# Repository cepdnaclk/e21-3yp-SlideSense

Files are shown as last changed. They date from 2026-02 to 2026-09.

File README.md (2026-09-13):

# SlideSense

### AI-Enhanced IoT Landslide Monitoring & Early Warning System

<p align="center">
  SlideSense Logo
</p>

<p align="center">
  <b>Early Detection. Safe Tomorrow.</b>
</p>

<p align="center">
  
  
  
  
</p>

<p align="center">
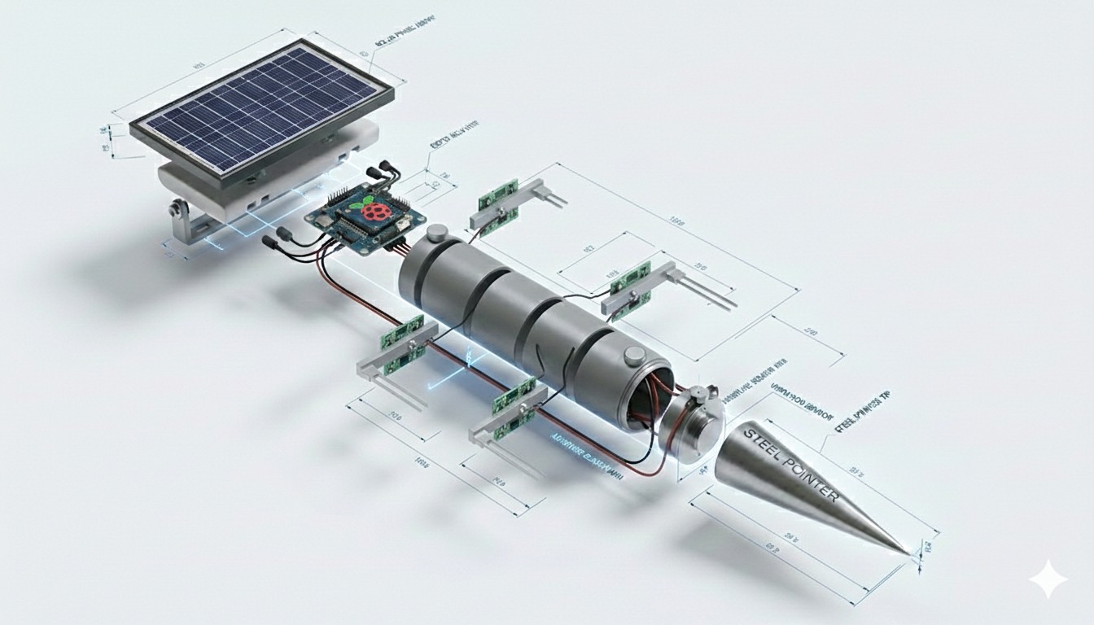
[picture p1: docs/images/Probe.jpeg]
SlideSense Sensor Probe
  
</p>

## Table of Contents

1. [Introduction](#introduction)
2. [Project Objectives](#project-objectives)
3. [System Overview](#system-overview)
4. [Overall System Architecture](#overall-system-architecture)
5. [Hardware Components](#hardware-components)
6. [Final Hardware Prototype](#final-hardware-prototype)
7. [Data Flow](#data-flow)
8. [Cloud Architecture](#cloud-architecture)
9. [Monitoring Dashboard](#monitoring-dashboard)
10. [Software & Technology Stack](#software--technology-stack)
11. [Testing & Validation](#testing--validation)
12. [Project Timeline](#project-timeline)
13. [Team](#team)
14. [Future Work](#future-work)
15. [Links](#links)

# Introduction

Landslides are a major natural hazard in mountainous and high-rainfall regions of Sri Lanka. Heavy rainfall and increasing soil moisture can gradually reduce slope stability and create potentially dangerous conditions.

**SlideSense** is an IoT-based landslide monitoring and early-warning system developed to continuously observe environmental conditions associated with landslide risk.

The system integrates:

- Multi-depth soil moisture sensing
- Rainfall monitoring
- ESP32-based embedded processing
- GPS positioning
- Cellular communication
- Solar-powered field operation
- AWS cloud infrastructure
- Historical sensor data storage
- Web-based monitoring and visualization
- Risk analysis and early-warning capabilities

SlideSense provides an end-to-end monitoring pipeline from the physical slope to a cloud-connected monitoring dashboard.

# Project Objectives

The main objective of SlideSense is to develop a practical IoT platform capable of continuously monitoring environmental parameters related to landslide risk.

The system aims to:

- Monitor soil moisture at multiple positions below the ground
- Measure rainfall continuously
- Collect and process sensor measurements using an ESP32
- Transmit field data to the cloud
- Store sensor measurements for future analysis
- Visualize real-time and historical data
- Identify potentially dangerous environmental conditions
- Support early-warning mechanisms
- Operate using an independent solar-powered field station

# System Overview

SlideSense consists of four major physical and software subsystems.

### 1. Subsurface Sensor Probe

The sensor probe is inserted into the monitored slope and contains soil moisture sensors positioned at different locations along the probe.

Measurements from multiple sensing points provide a better representation of subsurface soil conditions than a single surface measurement.

### 2. Rainfall Monitoring System

A tipping-bucket rain gauge measures accumulated rainfall.

A Hall-effect sensor detects each bucket tip.

Each tip corresponds to approximately:

> **0.173 mm of rainfall**

The ESP32 counts the detected tipping events and calculates the accumulated rainfall.

### 3. Main Control Unit

The main control unit contains the electronics required for sensor acquisition, communication, positioning, and power management.

The unit integrates:

- ESP32
- GPS module
- SIM / cellular communication module
- Buck converter
- MPPT solar charge controller
- Sensor connections
- Power-management circuitry

### 4. Web & Cloud Platform

Sensor measurements are transmitted to the cloud, where they can be processed, stored, analyzed, and accessed through the SlideSense monitoring dashboard.

# Overall System Architecture

The overall architecture connects the physical monitoring station with cloud services and the user-facing monitoring platform.

<p align="center">
  SlideSense Architecture
</p>

# Hardware Components

| Component | Function |
|---|---|
| **ESP32** | Main embedded controller |
| **Soil Moisture Sensors** | Monitor subsurface soil moisture |
| **Tipping Bucket Rain Gauge** | Measure accumulated rainfall |
| **Hall-Effect Sensor** | Detect tipping-bucket events |
| **GPS Module** | Obtain monitoring-node location |
| **SIM / Cellular Module** | Remote communication |
| **Solar Panel** | Renewable power source |
| **MPPT Charge Controller** | Manage solar charging |
| **Buck Converter** | Regulate supply voltage |
| **Battery** | Store energy for field operation |
| **Sensor Probe** | Houses subsurface sensing elements |
| **Main Control Unit** | Houses control and communication electronics |

# Final Hardware Prototype

## Sensor Probe

<p align="center">
  SlideSense Sensor Probe
</p>

The final SlideSense probe contains multiple soil moisture sensing positions.

The probe is designed to be placed vertically in the monitored ground so that environmental conditions can be measured below the surface.

## Tipping Bucket Rain Gauge

<p align="center">
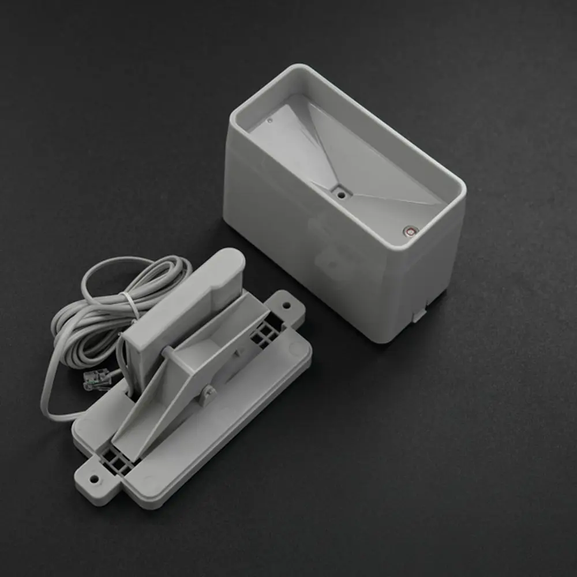
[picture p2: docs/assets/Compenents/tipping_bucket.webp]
SlideSense Tipping Bucket Rain Gauge
  
</p>

Rainfall is monitored using a tipping-bucket mechanism.

When the bucket tips, the Hall-effect sensor detects the event and sends it to the ESP32.

The system converts the number of detected tips into accumulated rainfall.

> **Rainfall per tip: approximately 0.173 mm**

## Main Control Unit

<p align="center">
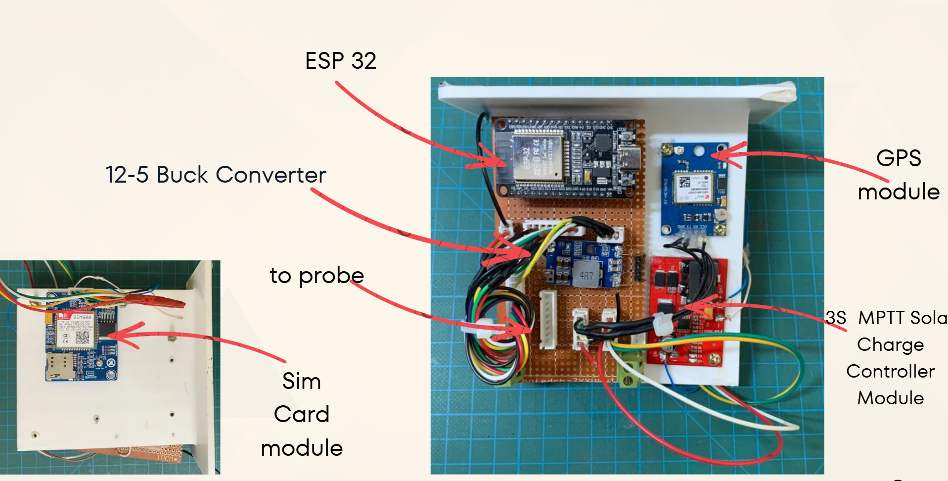
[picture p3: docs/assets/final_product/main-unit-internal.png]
SlideSense Main Control Unit
  
</p>

The main control unit integrates the electronic components required for data acquisition and communication.

Major components include:

- ESP32
- GPS module
- SIM / cellular module
- Buck converter
- MPPT solar charge controller
- Probe connection
- Power and sensor wiring

## Solar-Powered Field Station

<p align="center">
  SlideSense Solar Powered Field Station
</p>

The final SlideSense monitoring station combines the main control unit, solar panel, rainfall monitoring equipment, communication hardware, and underground sensor probe.

The solar-powered design allows the monitoring station to operate in locations where conventional power infrastructure may not be available.

# Data Flow

SlideSense follows an end-to-end IoT data pipeline.

```text
Environmental Conditions
          │
          ▼
   Physical Sensors
          │
          ▼
        ESP32
          │
          ▼
 Cellular Communication
          │
          ▼
     AWS IoT Core
          │
          ▼
   Cloud Processing
          │
     ┌────┴────┐
     │         │
     ▼         ▼
 Analysis   Database
     │         │
     └────┬────┘
          │
          ▼
    Web Dashboard
          │
          ▼
  Monitoring / Alerts
```

### Data Processing Steps

1. Soil moisture sensors measure subsurface conditions.
2. The tipping bucket measures rainfall.
3. The ESP32 collects the sensor measurements.
4. GPS information identifies the monitoring-node location.
5. Data is transmitted through the communication system.
6. Telemetry is published to AWS IoT Core using MQTT.
7. Cloud services process incoming measurements.
8. Sensor readings are stored for historical analysis.
9. The dashboard retrieves and displays the data.
10. Risk conditions can be evaluated to support early warnings.

# Cloud Architecture

The cloud layer connects the physical SlideSense field station with the monitoring dashboard.

## AWS IoT Core

AWS IoT Core receives telemetry published by the ESP32 using the MQTT protocol.

It provides the main communication entry point between the deployed monitoring station and cloud services.

## Cloud Processing

Incoming measurements can be processed to:

- Validate sensor readings
- Calculate derived measurements
- Analyze environmental conditions
- Evaluate configured thresholds
- Determine risk levels
- Trigger warning mechanisms

## Data Storage

Sensor readings are stored together with their timestamps.

This enables the system to support both:

**Real-Time Monitoring**

and

**Historical Data Analysis**

Historical measurements are particularly useful for identifying how environmental conditions change over longer periods.

# Monitoring Dashboard

SlideSense includes a dedicated web-based monitoring dashboard.

The dashboard provides a user-friendly interface for viewing and analyzing the measurements collected by the field station.

<p align="center">
  SlideSense Monitoring Dashboard
</p>

## Dashboard Features

### Real-Time Monitoring

The dashboard displays the latest measurements received from the field monitoring station.

### Sensor Charts

Sensor readings are visualized using time-series charts, making environmental changes easier to identify.

### Historical Data

Users can retrieve previously recorded measurements for further analysis.

### Trend Analysis

Current and historical readings can be compared to understand changes in environmental conditions.

### Risk Monitoring

Processed sensor information can be used to present the current environmental or landslide-risk condition.

## Live Dashboard

<p align="center">

[**Open SlideSense Live Dashboard →**](YOUR_DASHBOARD_URL)

</p>

# Software & Technology Stack

## Embedded System

- ESP32
- C / C++
- Arduino Framework
- Sensor interfacing
- MQTT communication
- GPS integration
- Cellular communication

## Cloud

- AWS IoT Core
- AWS Lambda
- DynamoDB
- MQTT

## Backend

- REST API
- Sensor-data retrieval
- Historical-data access
- Cloud integration
- Risk-analysis logic

## Frontend

- Web-based monitoring dashboard
- Responsive interface
- Real-time sensor visualization
- Time-series charts
- Historical data visualization
- Risk-status monitoring

<p align="center">
  SlideSense Software Stack
</p>

# Risk Analysis

SlideSense combines multiple environmental parameters to support landslide-risk analysis.

```text
        Soil Moisture
             +
          Rainfall
             +
   Environmental Data
             │
             ▼
       Data Analysis
             │
             ▼
      Risk Evaluation
             │
       ┌─────┼─────┐
       │     │     │
       ▼     ▼     ▼
    NORMAL MODERATE HIGH
             │
             ▼
       Warning System
```

Rather than depending on a single measurement, the system can evaluate multiple environmental conditions together.

# Testing & Validation

Testing was performed progressively from individual sensors to the complete cloud-connected system.

## Hardware Testing

Hardware verification included:

- Power and wiring checks
- Sensor connection testing
- ESP32 operation
- Soil moisture sensor response
- Tipping-bucket operation
- Hall-effect sensor detection
- GPS module communication
- Cellular communication
- Power-management testing
- Solar-system integration

## Soil Moisture Testing

The soil moisture sensors were tested under different moisture conditions.

Water was applied during testing and the corresponding changes in sensor readings were observed to verify sensor response.

## Rainfall Testing

The tipping bucket was tested using controlled water input.

Each physical bucket tip was checked against the corresponding digital event detected by the ESP32.

## Communication Testing

Sensor measurements were transmitted from the ESP32 to the cloud to verify the communication pipeline.

## Dashboard Testing

Cloud-stored measurements were retrieved and displayed through the monitoring dashboard.

## End-to-End Validation

The complete system was tested through the following path:

```text
Sensor
  ↓
ESP32
  ↓
Communication
  ↓
AWS IoT Core
  ↓
Cloud Processing
  ↓
Database
  ↓
Backend
  ↓
Web Dashboard
```

This verifies the complete flow from physical environmental measurement to user-facing visualization.

# Project Timeline

The project was completed through four major development milestones.

### Milestone 01
**Proposal & Planning**

- Problem identification
- Background research
- Initial system architecture
- Component selection

### Milestone 02
**Hardware Development & Testing**

- Sensor testing
- ESP32 integration
- Rainfall monitoring
- Probe development
- Communication testing

### Milestone 03
**Working Prototype**

- Hardware integration
- Cloud communication
- Data storage
- Backend development
- Dashboard development

### Milestone 04
**Final System**

- Final probe assembly
- Main control unit
- Solar-powered monitoring stand
- Dashboard integration
- System testing
- Documentation
- Final demonstration

# Team

SlideSense was developed as a Third-Year Project at the **Department of Computer Engineering, Faculty of Engineering, University of Peradeniya**.

| Reg. No. | Team Member | Email |
|---|---|---|
| **E/21/087** | Shihara Dewagedara | [e21087@eng.pdn.ac.lk](mailto:e21087@eng.pdn.ac.lk) |
| **E/21/138** | Fikry M.N.M. | [e21138@eng.pdn.ac.lk](mailto:e21138@eng.pdn.ac.lk) |
| **E/21/302** | Sahandi Perera | [e21302@eng.pdn.ac.lk](mailto:e21302@eng.pdn.ac.lk) |
| **E/21/452** | Zaid M.R.M. | [e21452@eng.pdn.ac.lk](mailto:e21452@eng.pdn.ac.lk) |

<p align="center">
  <b>Department of Computer Engineering</b><br>
  Faculty of Engineering<br>
  University of Peradeniya<br>
  Sri Lanka
</p>

# Future Work

SlideSense provides a foundation that can be extended through future research and development.

Potential improvements include:

- Machine-learning-based landslide-risk prediction
- Sensor-fusion-based risk estimation
- Long-term field deployment and validation
- Deployment of multiple monitoring stations
- Improved weather-resistant enclosures
- Additional geological sensors
- Advanced anomaly detection
- Mobile application development
- Location-based community warnings
- Integration with additional meteorological data
- Improved predictive models using historical datasets

# Links

### Project Website
🌐 [Visit the SlideSense Project Website](YOUR_PROJECT_WEBSITE_URL)

### Live Monitoring Dashboard
📊 [Open the SlideSense Dashboard](YOUR_DASHBOARD_URL)

### GitHub Repository
💻 [SlideSense Source Code](YOUR_GITHUB_REPOSITORY_URL)

---

<p align="center">
  SlideSense Logo
</p>

<p align="center">
  <b>SlideSense</b><br>
  AI-Enhanced IoT Landslide Monitoring & Early Warning System<br><br>
  Department of Computer Engineering<br>
  Faculty of Engineering<br>
  University of Peradeniya
</p>

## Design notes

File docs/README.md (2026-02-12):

---
layout: home
permalink: index.html
repository-name: e21-3yp-SlideSense
title: SlideSense
---

<p align="center">
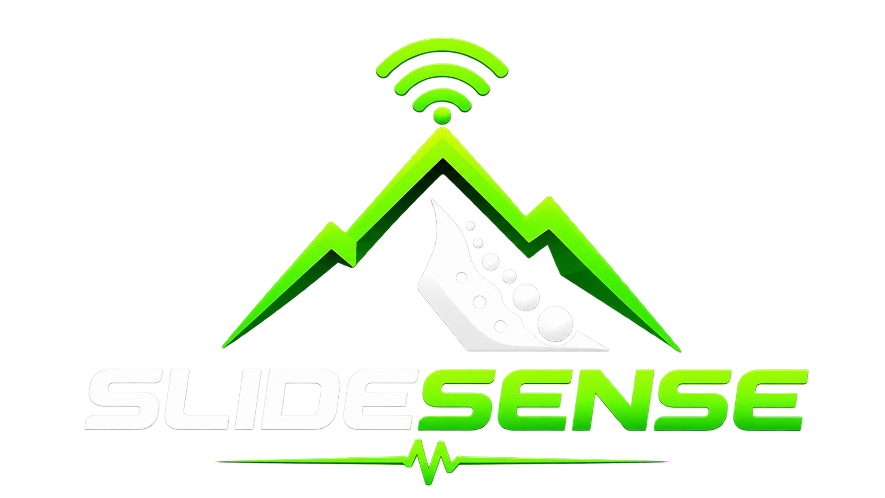
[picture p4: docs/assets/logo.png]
  
</p>

<p align="center">
  
</p>

<p align="center">
  
</p>

## Team
- E/21/087, Shihara Dewagedara, [e21087@eng.pdn.ac.lk](mailto:e21087@eng.pdn.ac.lk)
- E/21/138, Fikry M.N.M., [e21138@eng.pdn.ac.lk](mailto:e21138@eng.pdn.ac.lk)
- E/21/302, Sahandi Perera, [e21302@eng.pdn.ac.lk](mailto:e21302@eng.pdn.ac.lk)
- E/21/452, Zaid M.R.M., [e21452@eng.pdn.ac.lk](mailto:e21452@eng.pdn.ac.lk)

#### Table of Contents

1. [Introduction](#introduction)
2. [Overall System Architecture](#overall-system-architecture)
3. [Data Flow Architecture](#data-flow-architecture)
4. [Hardware Design](#hardware-design)
5. [Software Architecture & Stack](#software-architecture--stack)
6. [Project Timeline](#project-timeline)
7. [Testing & Validation](#testing--validation)
8. [Detailed Budget](#detailed-budget)
9. [Conclusion & Future Work](#conclusion--future-work)
10. [Links](#links)

## Introduction

Landslides remain a significant threat in hilly regions of Sri Lanka, often triggered by intense monsoon rainfall. **SlideSense** is an integrated IoT solution designed for real-time monitoring of high-risk slopes. 

The system moves beyond simple data logging by incorporating:
- **Redundant Communication:** Utilizing both Cloud (AWS/Firebase) and Local (Gateway) paths.
- **Edge Intelligence:** Real-time threshold analysis on the ESP32 to trigger immediate local sirens.
- **Resilience:** Designed to function even when external cellular networks fail during heavy storms.

## Overall System Architecture

SlideSense follows a **multi-layer IoT architecture**:

- **Perception Layer:** Distributed sensor nodes (ESP32) collect soil moisture, volumetric water content, and tilt data.
- **Network Layer:** Data is transmitted via MQTT protocol to a central Raspberry Pi gateway and subsequently to the AWS IoT Core.
- **Application Layer:** A React-based web dashboard and Firebase Cloud Messaging (FCM) provide localized alerts and historical data visualization for authorities.

<p align="center">
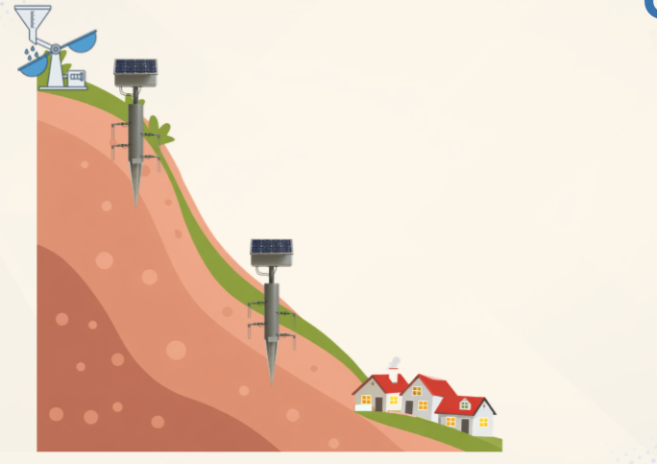
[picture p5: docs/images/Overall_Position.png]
  
</p>

## Data Flow Architecture

The system ensures reliable and redundant data transmission:

1. Sensors collect environmental data  
2. ESP32 performs edge analysis  
3. Data transmitted via LoRa / SIM900A  
4. Cloud (AWS/Firebase) processes & stores data  
5. Alerts triggered via Dashboard / SMS / FCM  

<p align="center">
  
</p>

##  Core Components

- **ESP32 WROOM 32U**
- **Capacitive Soil Moisture Sensors (x4)**
- **Tipping Bucket Rain Gauge**
- **High Sensitivity Microphone Sensor**
- **LoRa RA-02 SX1278 Module**
- **SIM900A GSM Module**
- **20W Solar Panel**
- **MPPT Charge Controller**
- **3.7V Li-Po Battery**

##  Power System

- MPPT Solar Charging
- 3.3V Regulation
- Deep Sleep Power Optimization

## Software Architecture & Stack

## Firmware
- Arduino Framework
- FreeRTOS Task Management
- MQTT Communication
- Deep Sleep Mode

##  Backend & Cloud
- AWS IoT Core / Firebase
- Mosquitto MQTT Broker
- Node.js Gateway (Optional)
- Firebase Cloud Messaging (Alerts)

##  Frontend
- React.js Dashboard
- Real-time Data Visualization
- Alert Monitoring Panel

## 🛠 Software Stack Diagram

<p align="center">
  
</p>

##  Project Timeline

The project was executed in four structured milestones:

- Milestone 01 – Proposal & Planning  
- Milestone 02 – Hardware Setup & Testing  
- Milestone 03 – Working Prototype  
- Milestone 04 – Final Product & Documentation  

<p align="center">
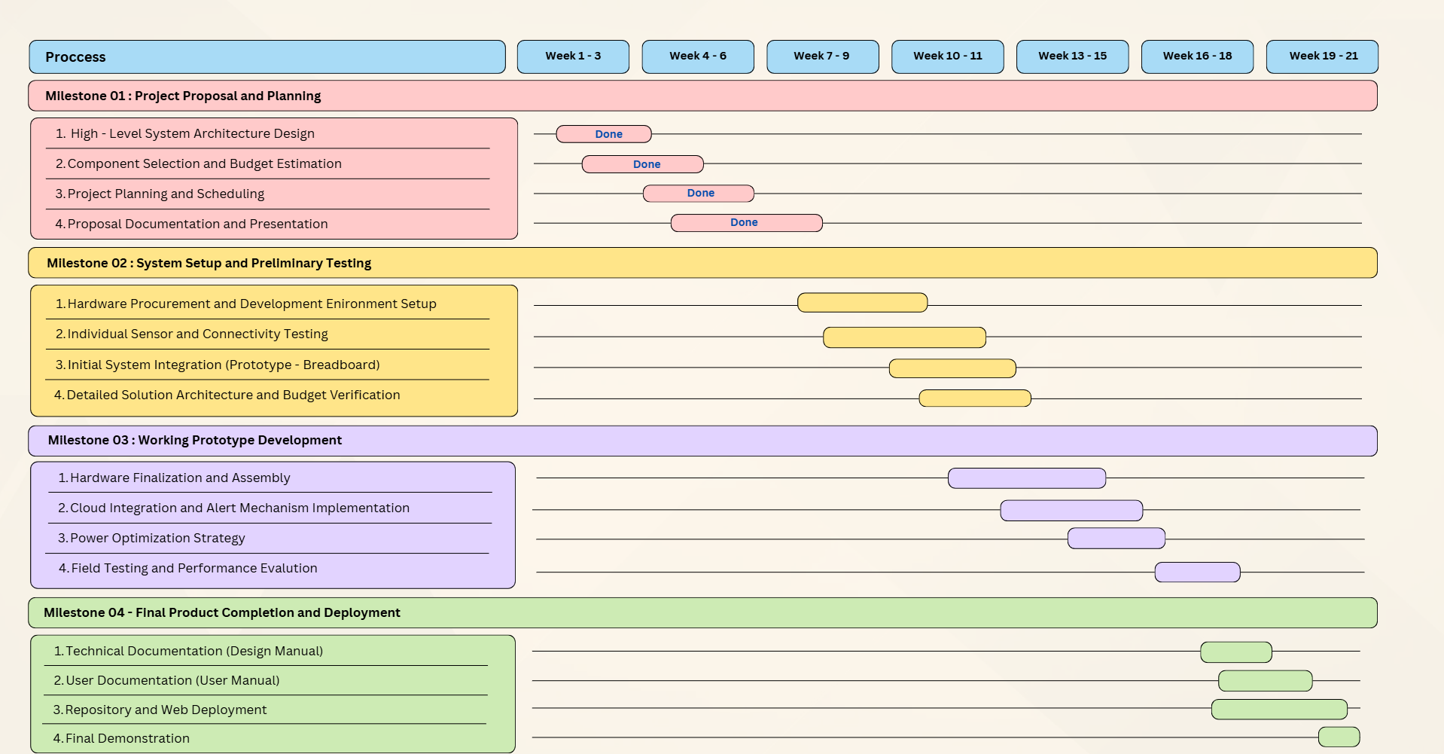
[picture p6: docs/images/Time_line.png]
  
</p>

## Testing & Validation

##  Hardware Testing
- Soil moisture calibration (dry vs saturated soil)
- Rain gauge pulse verification
- Battery discharge & deep sleep measurement

##  Connectivity Testing
- MQTT latency: < 2 seconds
- GSM fallback verification
- LoRa range testing in open field

##  Failover Testing
- Local gateway broadcast when WAN disconnected
- Alert triggering under simulated rainfall conditions

## Detailed Budget

| Item | Quantity | Unit Cost (LKR) | Total (LKR) |
| :--- | :---: | :---: | :---: |
| 20W Solar Panel | 1 | 3,350 | 3,350 |
| Li-Po Battery | 1 | 1,185 | 1,185 |
| MPPT Controller | 1 | 1,450 | 1,450 |
| Voltage Regulator | 1 | 120 | 120 |
| ESP32 | 1 | 1,860 | 1,860 |
| Soil Moisture Sensor | 4 | 290 | 1,160 |
| Tipping Bucket | 1 | 4,000 | 4,000 |
| LoRa Module | 1 | 1,500 | 1,500 |
| Microphone Sensor | 1 | 200 | 200 |
| SIM900A | 1 | 1,450 | 1,450 |
| **Total Cost** |  |  | **16,275 LKR** |

## Conclusion & Future Work

SlideSense demonstrates a **cost-effective, scalable, and resilient landslide monitoring system** integrating edge intelligence with cloud-based alerts.

### Future Enhancements
- LoRaWAN integration for extended mountainous coverage  
- Machine Learning (LSTM-based rainfall prediction)  
- IP67-rated rugged enclosure  
- Mobile application for public warning  

## Links

- [Project Repository](https://github.com/cepdnaclk/{{ page.repository-name }}){:target="_blank"}
- [Project Page](https://cepdnaclk.github.io/{{ page.repository-name}}){:target="_blank"}
- [Department of Computer Engineering](http://www.ce.pdn.ac.lk/)
- [University of Peradeniya](https://eng.pdn.ac.lk/)

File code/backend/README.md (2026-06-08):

# SlideSense Backend (Spring Boot)

This backend is initialized with:

- Java 21
- Spring Boot 3.5.13
- Maven wrapper
- Spring Web, Spring Data JPA, Validation, Actuator
- PostgreSQL + Flyway
- TimescaleDB-ready setup

## 1) Start local TimescaleDB

From this folder, run:

```bash
docker compose up -d
```

This creates:

- DB: `slidesense`
- User: `slidesense`
- Password: `slidesense`
- Port: `5432`

## 2) Build and test

```bash
./mvnw test
./mvnw -DskipTests package
```

The test profile excludes DB auto-configuration, so build checks run even if the DB is not running.

## 3) Run the app

```bash
./mvnw spring-boot:run
```

Defaults in `src/main/resources/application.properties` point to local TimescaleDB. Override via env vars if needed:

- `SPRING_DATASOURCE_URL`
- `SPRING_DATASOURCE_USERNAME`
- `SPRING_DATASOURCE_PASSWORD`
- `SERVER_PORT`

For a ready-to-edit template, copy `.env.example` to `.env` and adjust values for your machine.

Notes:

- `application.properties` is not a shell env file.
- It is the Spring Boot config file, and it can read environment variables using syntax like `${SPRING_DATASOURCE_URL:defaultValue}`.
- Use `.env` for local exported variables or editor tooling, and keep `.env.example` in git as the template.

## 4) Verify health

Open:

- `http://localhost:8080/actuator/health`

## 5) Swagger and security

- Swagger UI: `http://localhost:8080/swagger-ui.html`
- OpenAPI JSON: `http://localhost:8080/v3/api-docs`

Auth schemes:

- User APIs use Bearer JWT (`Authorization: Bearer <token>`)
- Public research APIs use API key header (`X-API-Key: <issued-key>`)

## 6) IntelliJ workflow

- Open the `code/backend` directory as a Maven project in IntelliJ.
- Use Maven tool window commands (`test`, `package`, `spring-boot:run`) or Run Configuration.

## 7) IntelliJ migration verification checklist

1. Start DB: `docker compose up -d`
2. Ensure schema is fresh only if needed:
  - Optional reset: `docker compose down -v` then `docker compose up -d`
3. Run app from IntelliJ (`BackendApplication`) or `./mvnw spring-boot:run`.
4. Confirm Flyway startup logs show `V1__enable_timescaledb.sql` and `V2__create_slidesense_schema.sql` applied (or already up to date).
5. Validate objects in PostgreSQL:
  - `\dt` should include relational tables and hypertables.
  - `\dm+` should show continuous aggregates.
  - `SELECT * FROM flyway_schema_history ORDER BY installed_rank;` should list V1 and V2 success.
6. Check API health: `http://localhost:8080/actuator/health`

## 8) Next for time-series schema

TimescaleDB extension is enabled through Flyway migration `V1__enable_timescaledb.sql`.
When you start defining your models, add a new migration to create hypertables, for example:

```sql
CREATE TABLE sensor_reading (
  id BIGSERIAL PRIMARY KEY,
  sensor_id TEXT NOT NULL,
  captured_at TIMESTAMPTZ NOT NULL,
  value DOUBLE PRECISION NOT NULL
);

SELECT create_hypertable('sensor_reading', 'captured_at', if_not_exists => TRUE);
```

## 9) Frontend Support Endpoints

New endpoints have been added to fully support the dynamic interactions required by the frontend application (`frontend-new`), replacing previously mocked data sources.

- **Probe Data (`ProbeDataController`)**
  - `GET /api/v1/probes/readings` - Returns paginated comprehensive sensor reading histories for all active probes.
  - `GET /api/v1/probes/latest` - Returns the latest captured snapshot for a specific probe.

- **Alerts (`AlertController`)**
  - `GET /api/v1/alerts` - Returns dynamically generated system alerts (e.g., critical movement detection based on tilt angle thresholds).

- **Dashboard Configurations (`DashboardController`)**
  - `GET /api/v1/dashboard/admin` - Returns admin thresholds, user lists, and security logs.
  - `GET /api/v1/dashboard/researcher` - Returns researcher analytics configurations.
  - `GET /api/v1/dashboard/resident` - Returns safety content and resident guidelines.
  - `GET /api/v1/dashboard/analytics-config` - Provides default metric options and time ranges for interactive graphs.

## 10) Authentication & Role-Based Access

The backend implements a robust, stateless JWT-based authentication system using Spring Security.

- **Login Flow**: Users authenticate via `POST /auth/login` by providing their `email` and `password`. The backend verifies the credentials against BCrypt password hashes in the database.
- **JWT Tokens**: Upon successful login, the backend issues an `accessToken` and `refreshToken` inside an `AuthResponse`. The frontend must include the access token in the `Authorization: Bearer <token>` header for all subsequent protected requests. The `AuthResponse` also cleanly returns the `user` object (including their `role`) so the frontend can properly route them to their dashboard.
- **Role-Based Access Control (RBAC)**: 
  - `JwtAuthenticationFilter` intercepts requests to validate the JWT and automatically populate the `SecurityContext`.
  - Endpoints are explicitly secured based on roles. For example, `GET /api/v1/probes/readings` requires `@PreAuthorize("hasRole('ADMIN') or hasRole('RESEARCHER')")` to prevent unauthorized broad data access.
  - Residents are restricted to `GET /api/v1/probes/my-readings`, where the `FrontendDataService` dynamically filters data to ensure they only receive readings for probes they have been explicitly granted access to via the `probe_access_grants` table.
- **CORS**: The application is configured with a global CORS policy allowing credentials, ensuring smooth communication between the React frontend and Spring Boot backend.

## 11) Soft Deletion of Probes

Probes (nodes) can be safely "removed" from the active system without deleting their historical data from the database.
- **Deactivation**: `DELETE /admin/probes/{probeId}` soft-deletes a probe by updating its `status` to `DEACTIVATED`. 
- **Data Integrity**: All associated `sensor_readings`, `rainfall_readings`, and `alerts` remain intact for historical queries.
- **Frontend Filtering**: The `FrontendDataService` automatically filters out `DEACTIVATED` probes from active live queries (`/api/v1/probes/readings` and `/api/v1/probes/my-readings`), ensuring removed nodes vanish from the active dashboard immediately.
- **Database Schema**: A new Flyway migration (`V5__add_deactivated_status_to_probes.sql`) modifies the PostgreSQL `CHECK` constraint on `probes.status` to safely permit the `DEACTIVATED` value.

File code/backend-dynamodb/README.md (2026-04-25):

# SlideSense DynamoDB Backend (Spring Boot)

A separate lightweight backend to read latest landslide sensor readings from DynamoDB.

## 1) What this provides

- `GET /api/landslide/latest` -> full latest record (m1, m2, m3, avg_moisture, rain, tilt, risk, lat, lng)
- `GET /api/landslide/latest/simple` -> simple key/value response (`moisture`, `rain`, `tilt`)
- `GET /api/landslide/health` -> health check

Default device ID is `LandslideProject/Prob01`, but you can override with query param:

- `/api/landslide/latest?deviceID=LandslideProject/Prob01`

## 2) AWS SDK dependency

Already added in [pom.xml](pom.xml):

- `software.amazon.awssdk:dynamodb:2.20.0`

## 3) Configure AWS credentials

Use one of these common options on your machine / server:

- Environment variables: `AWS_ACCESS_KEY_ID`, `AWS_SECRET_ACCESS_KEY`, `AWS_REGION`
- AWS profile in `~/.aws/credentials`
- IAM role (recommended for Elastic Beanstalk EC2)

The app uses region from `application.properties`:

- `app.dynamodb.region=ap-south-1`

## 4) Run locally

From this folder:

```bash
mvn clean package
mvn spring-boot:run
```

Test:

- `http://localhost:8080/api/landslide/latest`
- `http://localhost:8080/api/landslide/latest/simple`

## 5) Deploy to Elastic Beanstalk (Java platform)

1. Build JAR:
   - `mvn clean package`
2. Open AWS Elastic Beanstalk Console.
3. Create environment:
   - Tier: `Web server environment`
   - Platform: `Java`
   - Application code: upload `target/backend-dynamodb-0.0.1-SNAPSHOT.jar`
   - Preset: `Single instance (free tier eligible)`
4. IAM permissions (critical):
   - Find instance profile role used by Beanstalk (often `aws-elasticbeanstalk-ec2-role`)
   - Attach `AmazonDynamoDBReadOnlyAccess`

## 6) Optional env overrides in Beanstalk

Set these environment properties if needed:

- `APP_DYNAMODB_REGION=ap-south-1`
- `APP_DYNAMODB_TABLE_NAME=LandslideData`
- `APP_DYNAMODB_DEFAULT_DEVICE_ID=LandslideProject/Prob01`

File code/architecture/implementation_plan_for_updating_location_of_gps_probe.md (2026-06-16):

# Dynamic GPS Coordinates Update & Location Error Detection

## Background Context
Currently, probe coordinates (latitude and longitude) are only set/updated when the probe is initially created or when manually updated by an administrator via the map coordinate editor. GPS coordinates sent in probe telemetry readings are not tracked or saved.

We want to:
1. Automatically update the probe's location in the database when new telemetry readings arrive.
2. Detect if there is a "huge change" in coordinate values (exceeding a threshold of 0.01 degrees, i.e., ~1.1km).
3. If a huge change is detected, transition the probe status to `LOCATION_ERROR`, skip updating the coordinates, and make this visible in the frontend admin dashboard.
4. If the coordinates return to normal (within threshold), update them and revert status back to `ONLINE`.

---

## Proposed Changes

### Backend

#### [MODIFY] [ProbeStatus.java](file:///home/fikry/dev/e21-3yp-SlideSense/code/backend/src/main/java/com/slidesense/backend/model/enums/ProbeStatus.java)
- Add `LOCATION_ERROR` to the enum of probe statuses.

#### [MODIFY] [SqsSensorReadingMessage.java](file:///home/fikry/dev/e21-3yp-SlideSense/code/backend/src/main/java/com/slidesense/backend/dto/ingestion/SqsSensorReadingMessage.java)
- Add `latitude` and `longitude` fields to the SQS message record with `@JsonAlias` annotation supporting `lat`, `lng`, `latitude`, and `longitude`.

#### [MODIFY] [FrontendReadingDTO.java](file:///home/fikry/dev/e21-3yp-SlideSense/code/backend/src/main/java/com/slidesense/backend/dto/probe/FrontendReadingDTO.java)
- Add a `String status` field to the DTO so the frontend can receive the probe's current status (including `LOCATION_ERROR`).

#### [MODIFY] [FrontendDataService.java](file:///home/fikry/dev/e21-3yp-SlideSense/code/backend/src/main/java/com/slidesense/backend/service/FrontendDataService.java)
- Update instantiations of `FrontendReadingDTO` to populate the `status` field using `probe.getStatus().name()`.

#### [MODIFY] [SqsIngestionService.java](file:///home/fikry/dev/e21-3yp-SlideSense/code/backend/src/main/java/com/slidesense/backend/service/SqsIngestionService.java)
- In `processMessage`, if `message.latitude()` and `message.longitude()` are present:
  - If existing coordinates exist on the `Probe`:
    - Calculate absolute coordinate differences `diffLat` and `diffLng`.
    - If `diffLat > 0.01 || diffLng > 0.01`, set probe status to `LOCATION_ERROR`.
    - Otherwise, update probe's latitude and longitude and, if status was `LOCATION_ERROR`, revert it to `ONLINE`.
  - If no existing coordinates, update them directly and reset `LOCATION_ERROR` status if set.
  - Save the updated `Probe` entity.

#### [NEW] [SqsIngestionServiceTest.java](file:///home/fikry/dev/e21-3yp-SlideSense/code/backend/src/test/java/com/slidesense/backend/service/SqsIngestionServiceTest.java)
- Write unit tests for `SqsIngestionService` covering:
  - Coordinate update when no existing coordinates are present.
  - Normal coordinate update (within threshold).
  - Transition to `LOCATION_ERROR` when coordinate shift exceeds threshold.
  - Recovery to `ONLINE` and coordinate update when shifts fall back within threshold.

---

### Frontend

#### [MODIFY] [nodeService.js](file:///home/fikry/dev/e21-3yp-SlideSense/code/frontend-new/src/services/api/nodeService.js)
- Map the new `status` field from the reading data to the returned probe object.

#### [MODIFY] [NodesTab.jsx](file:///home/fikry/dev/e21-3yp-SlideSense/code/frontend-new/src/pages/admin/tabs/NodesTab.jsx)
- In the registered nodes table, render "Location Error" in red if `probe.status === 'LOCATION_ERROR'`.

#### [MODIFY] [ProbeDetailsPanel.jsx](file:///home/fikry/dev/e21-3yp-SlideSense/code/frontend-new/src/components/admin/ProbeDetailsPanel.jsx)
- Display a prominent error banner in the details panel when the selected probe has `status === 'LOCATION_ERROR'`.

---

## Verification Plan

### Automated Tests
- Run Backend unit/integration tests to verify that compilation and logic are correct:
  ```bash
  mvn test
  ```

### Manual Verification
- Trigger an HTTP ingestion message using `curl` with standard coordinates, and verify that the location coordinates update correctly on the database/frontend.
- Trigger an HTTP ingestion message with a large coordinate change, and verify that:
  - Status transitions to `LOCATION_ERROR`.
  - Coordinates are not modified.
  - The frontend displays "Location Error" on the nodes list and the details panel.

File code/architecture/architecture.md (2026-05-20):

# SlideSense — System Architecture

> IoT-Based Landslide Detection & Early Warning System

---

## 1. High-Level Overview

```
┌──────────────────────────────┐   MQTT    ┌──────────────────┐   IoT Rules  ┌────────────────┐
│  ESP32 / Raspberry Pi Node   ├─────────►│  AWS IoT Core     ├─────────────►│  AWS SQS Queue │
│  (Sensors + Wi-Fi + MQTT)    │          │  (Message Broker) │             │  (Buffer)      │
└──────────────────────────────┘          └──────────────────┘             └────────┬───────┘
                                                                                      │
                                                     ┌────────────────────────────────┘
                                                     │
                                                     ▼
                                          ┌──────────────────────┐
                                          │  SQS Consumer Worker │
                                          │  (Validation &       │
                                          │   Risk Analysis)     │
                                          └──────────┬───────────┘
                                                     │
                                    ┌────────────────┼─────────────────┐
                                    ▼                ▼                 ▼
                           ┌─────────────────┐ ┌──────────┐ ┌──────────────────┐
                           │   PostgreSQL +  │ │Notification│ Backend (FastAPI)
                           │   TimescaleDB   │ │  Service   │ on AWS EC2
                           │   (AWS RDS)     │ │(FCM/APNS)  │
                           └─────────────────┘ └──────────┘ └──────────┬───────┘
                                                                        │
                               ┌────────────────┬──────────────────────┤
                                ▼                ▼                      ▼
                       ┌──────────────────┐ ┌────────────────┐ ┌──────────────────┐
                       │  Mobile App      │ │  Admin Web     │ │  Research API    │
                       │  (Flutter)       │ │  Dashboard     │ │  /api/v1/public  │
                       │  HTTPS/REST      │ │  (React+Vite)  │ │  (API key auth)  │
                       └──────────────────┘ └────────────────┘ └──────────────────┘
```

**Telemetry flow:** ESP32/Raspberry Pi → MQTT → AWS IoT Core → IoT Rules Engine (routes to SQS) → SQS Queue → Spring Boot Backend (SQS Consumer) → Validation/Risk Analysis → DB Write + Notifications.

**API flow (external clients):** Mobile App, Admin Dashboard, Research API → Spring Boot Backend on EC2 → PostgreSQL + TimescaleDB.

---

ESP32 Payload structure
{
  "deviceTimeMs": 1716091208000, 
  "moisture": 45.2,
  "tiltAngle": 2.1,
  "vibrationMag": 0.05,
  "samplingMode": "ACTIVE",
  "rainfallMm": 12.5,
  "hwSerial": "ESP32-A1B2"
}

## 2. Database Structure

### 2.1 Schema Design

Two logical partitions inside a single PostgreSQL + TimescaleDB instance on AWS RDS.

#### A. Time-Series Store (TimescaleDB Hypertables)

```sql
-- Core sensor readings — converted to a hypertable on `recorded_at`
CREATE TABLE sensor_readings (
    id              BIGSERIAL,
    probe_id        UUID        NOT NULL REFERENCES probes(id),
    recorded_at     TIMESTAMPTZ NOT NULL,
    moisture        REAL,           -- % saturation
    tilt_angle      REAL,           -- degrees
    vibration_mag   REAL,           -- m/s²
    sampling_mode   VARCHAR(10)     -- 'normal' | 'burst'
);
SELECT create_hypertable('sensor_readings', 'recorded_at');

-- Rainfall readings — only probes with a rainfall gauge will publish these
CREATE TABLE rainfall_readings (
    id              BIGSERIAL,
    probe_id        UUID        NOT NULL REFERENCES probes(id),
    recorded_at     TIMESTAMPTZ NOT NULL,
    rainfall_mm     REAL
);
SELECT create_hypertable('rainfall_readings', 'recorded_at');

-- Continuous aggregate for dashboards / research API
CREATE MATERIALIZED VIEW sensor_aggregates
WITH (timescaledb.continuous) AS
SELECT
    probe_id,
    time_bucket('1 hour', recorded_at) AS bucket,
    AVG(moisture)      AS avg_moisture,
    MAX(vibration_mag) AS max_vibration
FROM sensor_readings
GROUP BY probe_id, bucket;

-- Continuous aggregate for rainfall-specific dashboards / research API
CREATE MATERIALIZED VIEW rainfall_aggregates
WITH (timescaledb.continuous) AS
SELECT
    probe_id,
    time_bucket('1 hour', recorded_at) AS bucket,
    SUM(rainfall_mm)   AS total_rainfall
FROM rainfall_readings
GROUP BY probe_id, bucket;
```

#### B. Relational Store (Standard PostgreSQL Tables)

```sql
CREATE TABLE users(
    id              UUID PRIMARY KEY DEFAULT gen_random_uuid(),
    email           VARCHAR(255)    UNIQUE NOT NULL,
    full_name       VARCHAR(160)    NOT NULL,
    phone_number    VARCHAR(30),
    address         TEXT,
    password_hash   TEXT            NOT NULL,       -- bcrypt
    role            VARCHAR(20)     NOT NULL DEFAULT 'resident',
                                    -- resident | admin | researcher
    registration_status VARCHAR(20)  NOT NULL DEFAULT 'pending',
                                   -- pending | approved | rejected | suspended
    approved_by     UUID            REFERENCES users(id),
    approved_at     TIMESTAMPTZ,
    created_at      TIMESTAMPTZ     DEFAULT now()
);

CREATE TABLE devices (
    id              UUID PRIMARY KEY DEFAULT gen_random_uuid(),
    user_id         UUID            NOT NULL REFERENCES users(id),
    device_token    TEXT            NOT NULL,       -- FCM / APNS push token
    is_active       BOOLEAN         DEFAULT true,
    registered_at   TIMESTAMPTZ     DEFAULT now()
);

CREATE TABLE probes (
    id              UUID PRIMARY KEY DEFAULT gen_random_uuid(),
    hw_serial       VARCHAR(64)     UNIQUE NOT NULL,
    firmware_ver    VARCHAR(20),
    latitude        DOUBLE PRECISION,
    longitude       DOUBLE PRECISION,
    status          VARCHAR(20)     DEFAULT 'online',  -- online | offline | maintenance
    installed_at    TIMESTAMPTZ     DEFAULT now()
);

CREATE TABLE registration_requests (
    id              UUID PRIMARY KEY DEFAULT gen_random_uuid(),
    user_id         UUID            NOT NULL REFERENCES users(id),
    requested_role  VARCHAR(20)     NOT NULL DEFAULT 'resident',
                                   -- resident | researcher
    probe_id        UUID            REFERENCES probes(id),
    reason          TEXT            NOT NULL,
    verification_notes TEXT,
    status          VARCHAR(20)     NOT NULL DEFAULT 'pending',
                                   -- pending | approved | rejected
    reviewed_by     UUID            REFERENCES users(id),
    reviewed_at     TIMESTAMPTZ,
    created_at      TIMESTAMPTZ     DEFAULT now(),
    CHECK (
        (requested_role = 'resident' AND probe_id IS NOT NULL) OR
        (requested_role = 'researcher' AND probe_id IS NULL)
    )
);

CREATE TABLE probe_access_grants (
    id              UUID PRIMARY KEY DEFAULT gen_random_uuid(),
    user_id         UUID            NOT NULL REFERENCES users(id),
    probe_id        UUID            NOT NULL REFERENCES probes(id),
    granted_by      UUID            NOT NULL REFERENCES users(id),
    granted_at      TIMESTAMPTZ     NOT NULL DEFAULT now(),
    revoked_at      TIMESTAMPTZ,
    -- Resident-specific probe grants; researchers are authorized by role.
    UNIQUE (user_id, probe_id)
);

CREATE TABLE alerts (
    id              UUID PRIMARY KEY DEFAULT gen_random_uuid(),
    probe_id        UUID            NOT NULL REFERENCES probes(id),
    level           SMALLINT        NOT NULL,       -- 1=Normal, 2=Warning, 3=Dangerous
    triggered_at    TIMESTAMPTZ     NOT NULL,
    resolved_at     TIMESTAMPTZ,
    details         JSONB
);

CREATE TABLE api_keys (
    id              UUID PRIMARY KEY DEFAULT gen_random_uuid(),
    owner_email     VARCHAR(255)    NOT NULL,
    key_hash        TEXT            NOT NULL,       -- SHA-256 of the issued key
    rate_limit      INT             DEFAULT 100,    -- requests/hour
    scopes          TEXT[]          DEFAULT '{read}',
    expires_at      TIMESTAMPTZ,
    created_at      TIMESTAMPTZ     DEFAULT now()
);
```

### 2.2 Data Retention Policy

| Granularity | Retention | Purpose |
|---|---|---|
| Raw readings (10 s – 15 min) | 90 days | Incident forensics |
| Aggregated readings | 2 years | Trend analysis / Research API |
| Daily aggregates | Indefinite | Long-term geological study |

Implemented via TimescaleDB `add_retention_policy()`.

---

## 3. Backend Software Architecture

### 3.1 Component Map

```
┌──────────────────────────────────────────────────────────────────────────┐
│                         AWS Environment                                  │
│                                                                          │
│  ┌──────────────────┐                                                   │
│  │  AWS IoT Core    │  IoT Rules Engine                                 │
│  │  (MQTT Broker)   ├──────────────────────────┐                       │
│  └──────────────────┘                          │                       │
│                                                  ▼                       │
│                                        ┌─────────────────┐              │
│                                        │   AWS SQS       │              │
│                                        │   Queue         │              │
│                                        └────────┬────────┘              │
│                                                  │                       │
│  ┌────────────────────────────────────────────────────────────────┐   │
│  │            Spring Boot Application (AWS EC2)                 │   │
│  │                                                               │   │
│  │  ┌──────────────────┐        ┌────────────────────────┐     │   │
│  │  │ SQS Consumer     │        │  Validation &          │     │   │
│  │  │ (Spring AWS SDK) ├───────►│  Normalisation         │     │   │
│  │  │ (Long polling)   │        │  + Risk Analysis       │     │   │
│  │  └──────────────────┘        └──────────┬─────────────┘     │   │
│  │                                          │                   │   │
│  │           ┌───────────────────────────────┼──────────┐       │   │
│  │           ▼                               ▼          ▼       │   │
│  │     ┌──────────┐              ┌────────┐ ┌──────────────┐  │   │
│  │     │Notification Service    │ DB     │ │ Cache (Redis)│  │   │
│  │     │(FCM/APNS + SMS/SNS)    │ Writer │ │              │  │   │
│  │     └──────────┘              └────────┘ └──────────────┘  │   │
│  │                                                               │   │
│  │  ┌────────────────────────────────────────────────────┐     │   │
│  │  │  Spring Boot REST Controllers (External APIs)      │     │   │
│  │  │  @RestController /auth  /data  /alerts  /admin    │     │   │
│  │  │  /api/v1/public (Research API)                     │     │   │
│  │  └────────────────────────────────────────────────────┘     │   │
│  │                                                               │   │
│  └───────────────────────────────────────────────────────────────┘  │
│                                                                      │
│  ┌──────────────────────────┐                  ┌──────────────────────┐ │
│  │  PostgreSQL +            │                  │ ElastiCache Redis    │ │
│  │  TimescaleDB (RDS)       │                  │                      │ │
│  └──────────────────────────┘                  └──────────────────────┘ │
└──────────────────────────────────────────────────────────────────────────┘
```

### 3.2 Core Services (Spring Boot / Java)

| Service | Responsibility |
|---|---|
| **SQS Consumer Service** | Implements `@Service` with `@SqsListener` (Spring Cloud AWS). Long-polls SQS for telemetry messages. Uses AWS SDK to receive, deserialize, and validate JSON payloads (schema + HMAC signature). Deletes message only after successful processing. |
| **Validation & Normalisation** | Rejects out-of-range values, converts units, tags `sampling_mode`. Implemented as utility functions. |
| **Risk Analysis Engine** | Applies 3-level alert logic via business logic layer. If vibration + moisture exceed thresholds → level 3 alert. Runs as an async/threaded task. |
| **Notification Service** | Pushes FCM (Android) / APNS (iOS) notifications via Firebase Admin SDK. Escalates level 3 to SMS via AWS SNS. |
| **DB Writer** | Batch-inserts readings into TimescaleDB using JPA/Hibernate repositories. Writes alerts to the `alerts` table. |
| **Redis Cache** | Stores latest reading per probe using Spring Data Redis. Caches JWT blacklist for logout. |

### 3.3 API Route Groups (Spring Boot Controllers)

```
@RestController
@RequestMapping("/auth")
    POST   /register          — sign up as pending user (resident/researcher, requires admin verification)
    POST   /login             — returns JWT access + refresh tokens after approval
    POST   /refresh           — rotate access token
    POST   /logout            — blacklists refresh token

@RestController
@RequestMapping("/data")
    GET    /probes/{id}/live  — latest cached reading (Redis; residents must be granted, researchers can query all)
    GET    /probes/{id}/history?range=7d  — time-series query (residents: granted probes only, researchers: all)
    GET    /dashboard         — aggregated stats for authorized probes

@RestController
@RequestMapping("/alerts")
    GET    /alerts            — paginated alert history
    POST   /alerts/{id}/ack  — admin acknowledges an alert

@RestController
@RequestMapping("/admin")  (role: admin)
    GET    /probes            — all probe statuses
    PUT    /probes/{id}/config — update thresholds / sampling mode
    GET    /users             — user management
    GET    /registration-requests   — review pending resident/researcher requests
    POST   /registration-requests/{id}/approve — approve requested role + access scope
    POST   /registration-requests/{id}/reject  — reject registration request

@RestController
@RequestMapping("/api/v1/public")  (API key auth, read-only)
    GET    /rainfall-history?region=&from=&to=
    GET    /soil-saturation?region=&from=&to=
```

### 3.4 Device Communication Protocol

#### Device → Cloud (MQTT)
- **Transport:** MQTT over TLS (port 8883) via AWS IoT Core.
- **Topic schema:** `probes/{probe_id}/telemetry` (publish), `probes/{probe_id}/cmd` (subscribe for config updates).
- **Payload (JSON):**

```json
{
  "probe_id": "uuid",
  "ts": "2026-03-12T08:30:00Z",
  "moisture": 72.5,
  "tilt_angle": 0.3,
  "vibration": 0.04,
  "rainfall_mm": 2.1,
  "mode": "normal",
  "hmac": "sha256-signature"
}
```

`rainfall_mm` is only included by probes with a rainfall gauge installed; other probes publish sensor telemetry without it.

#### IoT Core → SQS (AWS Rules Engine)
- **Routing:** AWS IoT Core Rules Engine inspects incoming MQTT messages on `probes/+/telemetry` and republishes to SQS queue.
- **Queue URL:** `https://sqs.{region}.amazonaws.com/{account}/slidesense-telemetry`
- **Message format:** MQTT payload is wrapped in SQS message with attributes (probe_id, timestamp extracted for indexing).
- **Retention:** SQS messages expire after 14 days (standard queue); consumer must process within this window.

#### SQS → Backend Consumer
- **Consumer:** Runs as a long-running process on EC2 (or Fargate task).
- **Polling:** `receive_message(MaxNumberOfMessages=10, WaitTimeSeconds=20)` — batch pull with long polling.
- **Processing:** Validate, normalize, run risk analysis, write to DB, send notifications.
- **Visibility timeout:** 5 minutes — if consumer crashes before `delete_message()`, message returns to queue.
- **Dead letter queue (DLQ):** Messages that fail after 3 retries go to DLQ for manual inspection.

### 3.5 Sampling Mode Switching

| Condition | Action |
|---|---|
| All values normal | 15-min interval (`normal`) |
| Any single threshold crossed | 1-min interval (`elevated`) |
| Vibration **and** moisture critical | 10-sec interval (`burst`) — triggers level 3 alert |

Switching is commanded server-side via `probes/{id}/cmd` or locally by the Raspberry Pi node software.

---

## 4. Mobile App Architecture

### 4.1 Platform & Framework

- **Flutter** (single codebase for Android & iOS).
- Native platform channels for: background alarm audio, Wi-Fi SSID detection, local notifications.

### 4.2 Dual-Connection Model

```
┌─────────────────────────────────────────────┐
│                  Mobile App                 │
│                                             │
│              Remote Mode                    │
│             (HTTPS/REST)                    │
│              ◄──► Cloud API                 │
│                   via 4G/5G                │
│                                             │
│         ┌──────────────────┐                │
│         │  Unified Data    │                │
│         │  Layer (BLoC)    │                │
│         └──────────────────┘                │
└─────────────────────────────────────────────┘
```

| Mode | Trigger | Data Source | Latency |
|---|---|---|---|
| **Mode A — Remote (Internet Link)** | Normal operation | Cloud API (approved probe data + historical) | 1–3 s |

Access is granted only after admin approval; the app no longer uses local probe Wi-Fi sharing or local device auth.

### 4.3 State Management & Layers

```
Presentation (UI)
    └── BLoC / Cubit  (state management)
           └── Repository Layer (abstracts data source)
                  ├── RemoteDataSource (REST to Cloud API)
                  └── CacheDataSource  (SQLite / Hive for offline)
```

### 4.4 Key Features

| Feature | Implementation |
|---|---|
| **Real-time dashboard** | Server-Sent Events or WebSocket stream from the cloud API. |
| **Emergency alarm** | Foreground service (Android) / background mode (iOS). Plays alarm audio even when phone is locked. |
| **Deep analysis charts** | Pulled from cloud; rendered with `fl_chart`. |
| **Access control** | Admin-approved registration grants residents probe-scoped access and researchers full-probe analytical access. |
| **Offline cache** | Last 24 h of approved probe readings stored locally in SQLite for zero-connectivity scenarios. |
| **Push notifications** | FCM (Android) + APNS (iOS) for warning/danger alerts. |

### 4.5 User Registration & Verification Flow

```
1. User signs up from the app with profile details like name, phone number, and address, and chooses resident or researcher onboarding.
2. A registration request is created and stays pending for admin review.
3. If resident, the request targets a specific probe; if researcher, the request is global (no single probe binding).
4. Admin manually verifies and approves or rejects the request.
5. Approved residents access only granted probes; approved researchers can access aggregated data across all probes.
```

---

## 5. Admin Web Dashboard

- **Stack:** React + Vite, TanStack Query, Leaflet (maps), Recharts (graphs).
- **Auth:** Same JWT-based auth; requires `admin` role.
- **Features:** Real-time probe map, threshold configuration, user management, alert history with acknowledge workflow.

---

## 6. Research API

- Separate route group `/api/v1/public` — no user PII exposed.
- **Auth:** API key (hashed in `api_keys` table), passed via `X-API-Key` header.
- **Rate limit:** Configurable per key (default 100 req/hr) enforced by Redis sliding window.
- **Data:** Returns only aggregated environmental metrics (rainfall, soil saturation) — never user data or precise probe GPS.

---

## 7. Security Architecture

### 7.1 Authentication & Authorization

| Layer | Mechanism |
|---|---|
| Mobile ↔ Cloud | JWT (RS256) access + refresh tokens. Access token TTL: 15 min. Refresh TTL: 7 days. Refresh rotation on every use. |
| Raspberry Pi ↔ AWS IoT Core | Mutual TLS (X.509 certificates per device). |
| Admin Dashboard | JWT + role-based access control (`admin` role required). |
| Resident probe access | Admin-approved account status plus probe-specific grant records. |
| Researcher access | Admin-approved researcher registration with role-based permission to query all probes (read-only analytics scope). |
| Research API | HMAC-SHA256 API keys, rate-limited, read-only scope. |

### 7.2 Data Protection

| Concern | Measure |
|---|---|
| **Transport encryption** | TLS 1.3 on all HTTPS and MQTT connections. |
| **Data at rest** | AWS RDS encryption (AES-256). Encrypted EBS volumes. |
| **Password storage** | bcrypt with cost factor ≥ 12. |
| **Secrets management** | AWS Secrets Manager for DB credentials, JWT signing keys, IoT certs. |
| **PII minimisation** | Research API returns only environmental aggregates — no user/location data. |

### 7.3 Device & Network Security

| Concern | Measure |
|---|---|
| **Probe authentication** | Each Raspberry Pi has a unique X.509 cert; revocable via AWS IoT Core. |
| **Payload integrity** | HMAC-SHA256 signature on every MQTT payload; rejected if invalid. |
| **Registration control** | Admin verifies each resident/researcher account before login is enabled. |
| **Probe access control** | Access to probe data is granted per user and probe through explicit approval records. |
| **Researcher scope control** | Researcher role is manually approved and restricted to read-only analytical access. |
| **Anti-theft** | Tamper-detect circuit; optional low-voltage deterrent on enclosure. |

### 7.4 Application Security

| Concern | Measure |
|---|---|
| **Input validation** | Pydantic models in FastAPI — strict schema validation on all endpoints. |
| **SQL injection** | Parameterized queries via SQLAlchemy ORM — no raw string interpolation. |
| **Rate limiting** | Global rate limit (Nginx) + per-key limit for Research API (Redis). |
| **CORS** | Allowlist of dashboard and app origins only. |
| **Dependency scanning** | Automated `pip-audit` / `npm audit` in CI. |
| **JWT blacklist** | Revoked refresh tokens stored in Redis with TTL matching token expiry. |
| **Secure storage (mobile)** | JWT refresh tokens and session secrets stored in Android Keystore / iOS Keychain — never in plain-text. |

### 7.5 Monitoring & Incident Response

- **CloudWatch** alarms for anomalous MQTT throughput, API error rates, DB connection spikes.
- Alert-level escalation: level 3 events auto-notify admin via SMS (AWS SNS) + email.
- Audit log table for admin actions (user management, threshold changes).

---

## 8. Deployment Overview

```
GitHub Actions CI/CD
    ├── Lint + Test + Security Scan
    ├── Build Maven JAR → push to ECR (Docker image)
    └── Deploy services:
        └── Spring Boot app to EC2 (blue/green via CodeDeploy)
           - Runs SQS Consumer (via @SqsListener)
           - Serves REST API (@RestController endpoints)

Infrastructure (Terraform)
    ├── VPC + subnets (public/private)
    ├── AWS IoT Core (device registry + rules engine → SQS routing)
    ├── AWS SQS Queue (telemetry buffer)
    ├── EC2 (Spring Boot) in private subnet behind ALB
    │   └── Embedded SQS consumer + REST API server
    ├── RDS PostgreSQL (TimescaleDB) in private subnet
    ├── ElastiCache Redis
    └── S3 (firmware OTA binaries)
```

---

## 9. Technology Summary

| Component | Technology |
|---|---|
| Node controller | ESP32 / Raspberry Pi (sensors connected via GPIO / I2C / SPI) |
| Node-to-Cloud comms | MQTT over TLS (Wi-Fi / Ethernet) |
| Message Broker | AWS IoT Core (MQTT) |
| Queue | AWS SQS (telemetry buffer) |
| Backend language | Java 17+ |
| API framework | Spring Boot 3.x |
| Queue consumer | Spring Cloud AWS (SQS) |
| Database | PostgreSQL 16 + TimescaleDB |
| Cache | Redis (Spring Data Redis) |
| ORM | Spring Data JPA / Hibernate |
| Mobile app | Flutter (Android + iOS) |
| Admin dashboard | React + Vite |
| Cloud platform | AWS (EC2, RDS, IoT Core, SNS, SQS, S3) |
| IaC | Terraform |
| CI/CD | GitHub Actions |

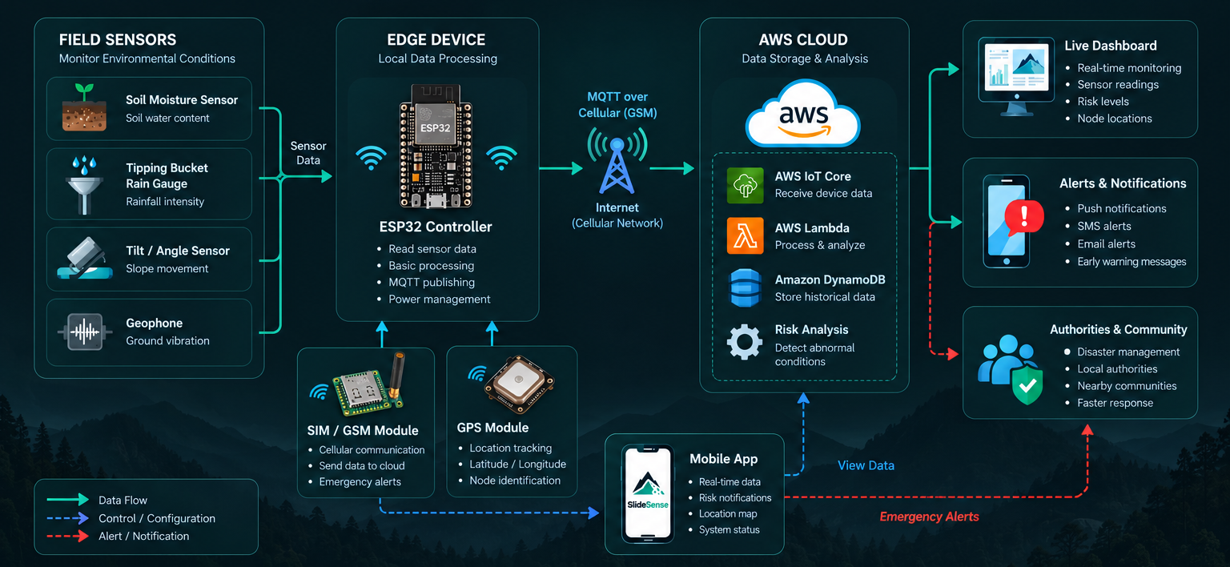
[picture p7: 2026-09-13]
docs/assets/architecture/arch.png

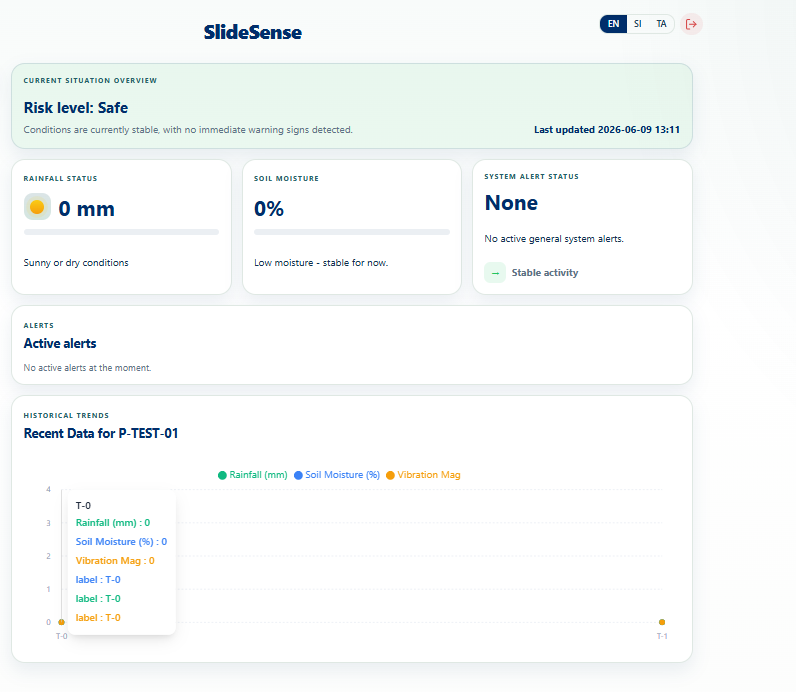
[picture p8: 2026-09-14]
docs/assets/dashboard/chart.png

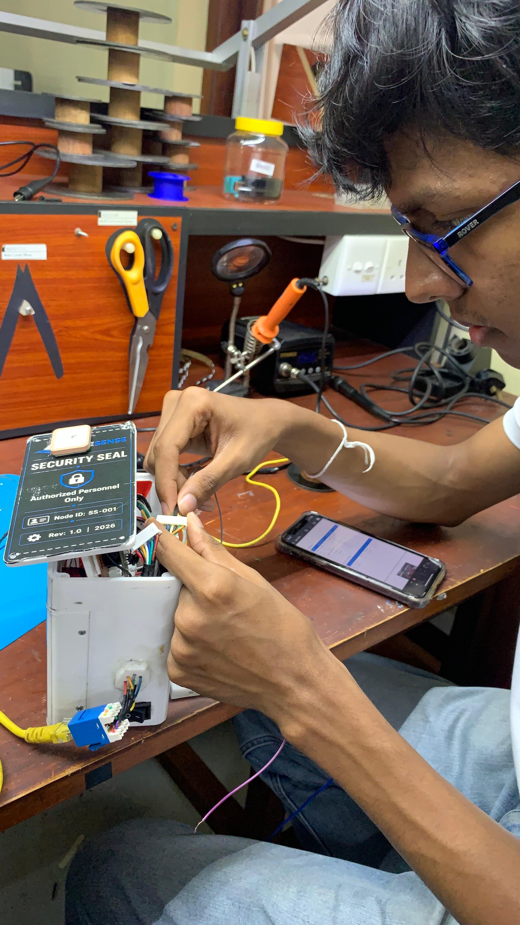
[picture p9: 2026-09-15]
docs/assets/images/workbench_2.jpeg

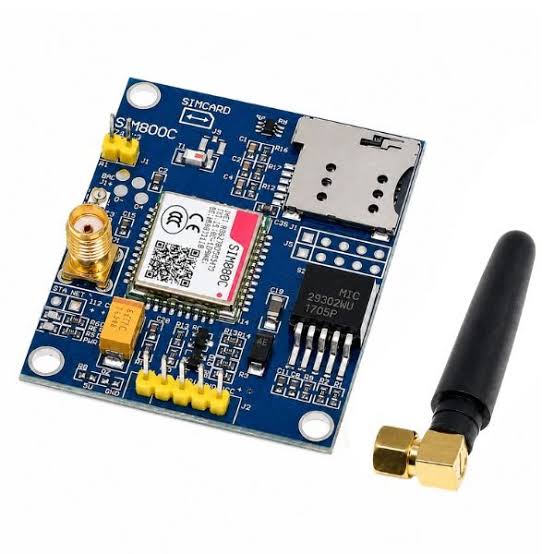
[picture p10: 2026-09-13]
docs/assets/Compenents/sim_card.jpg

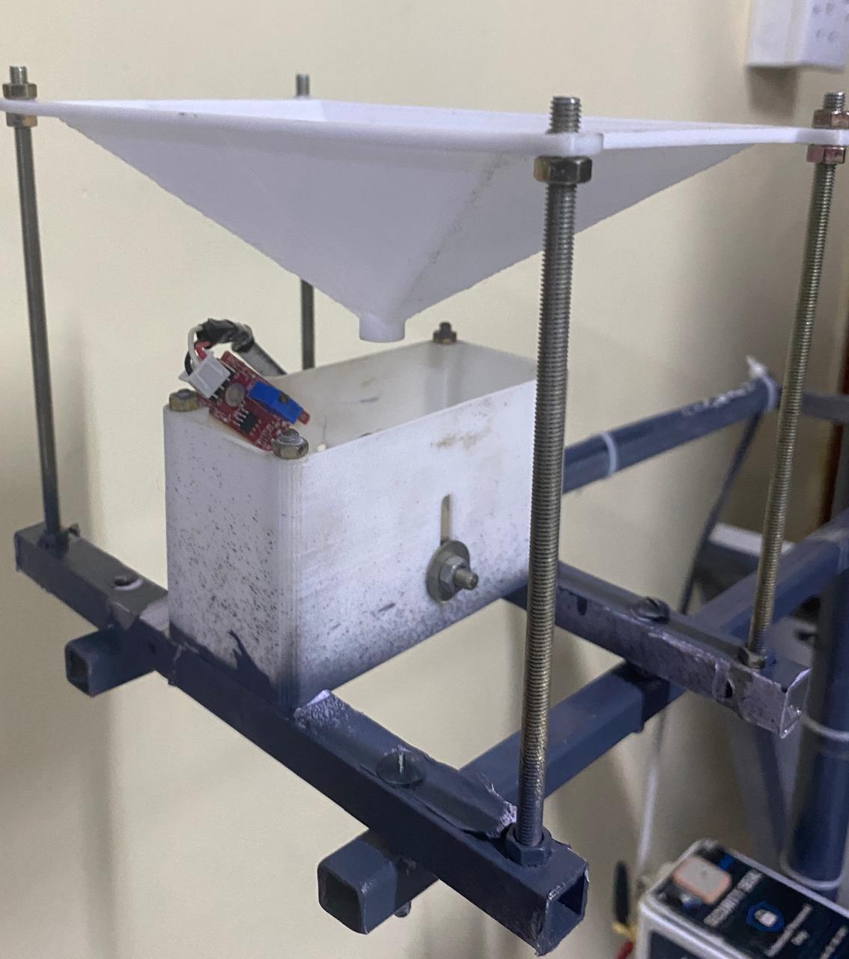
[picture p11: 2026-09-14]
docs/assets/final_product/tipping_bucket.jpeg

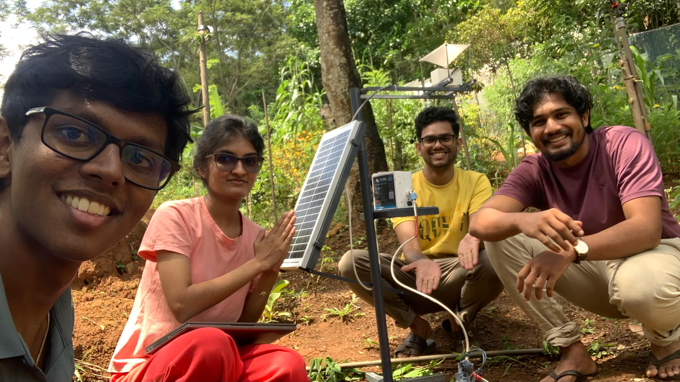
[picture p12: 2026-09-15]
docs/assets/images/team.jpeg

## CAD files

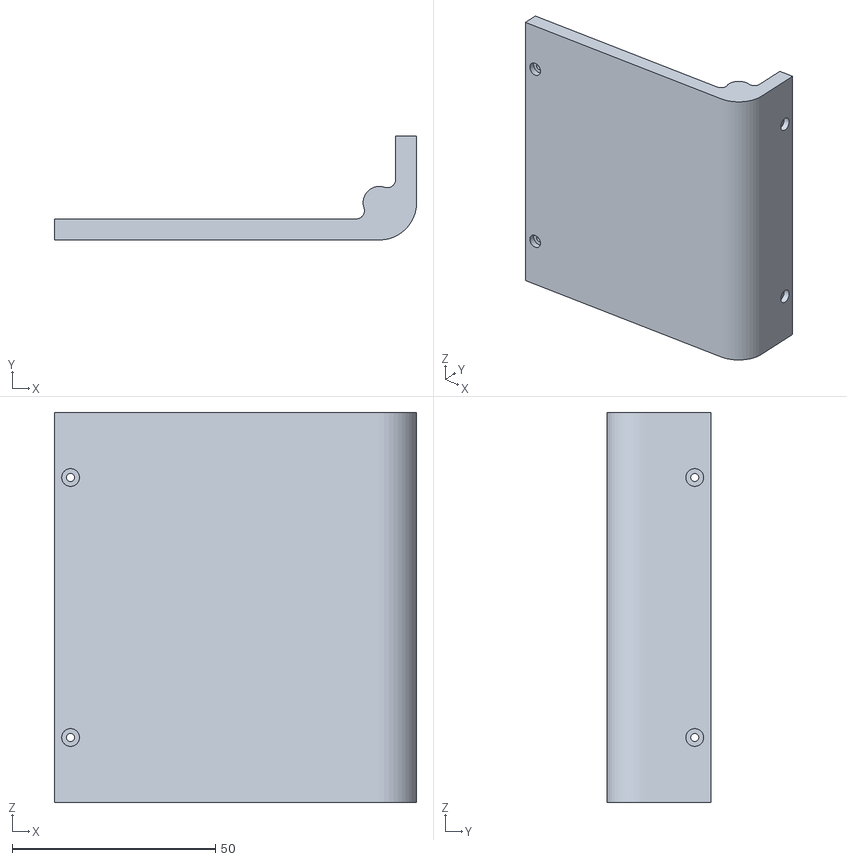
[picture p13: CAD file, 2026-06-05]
Hardware Components/Box/Battery Lid.stl
89.2 x 25.6 x 96.0

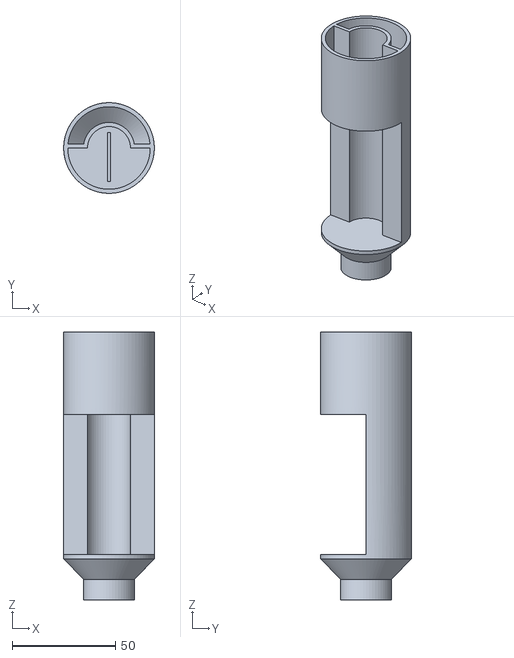
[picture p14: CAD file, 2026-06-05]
Hardware Components/Probe/Sensor Enclosure.stl
44.0 x 44.0 x 130.0

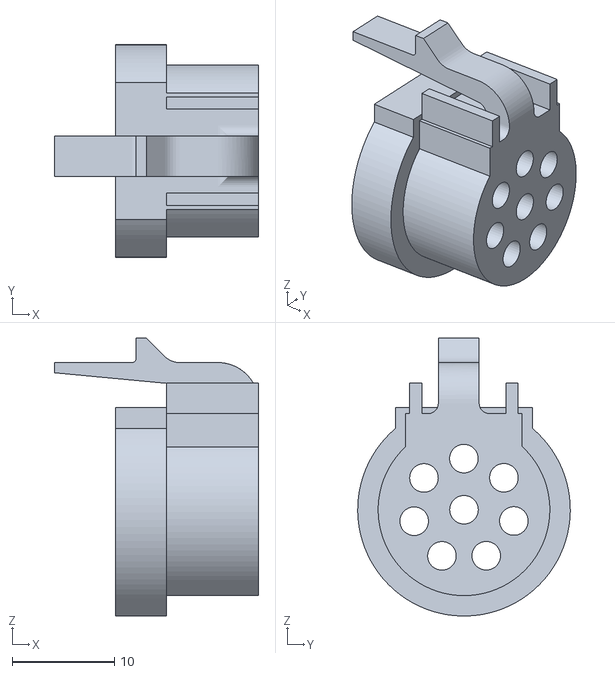
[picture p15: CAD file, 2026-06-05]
Hardware Components/Socket/Male Plug 8 pin.stl
20.0 x 20.8 x 27.2

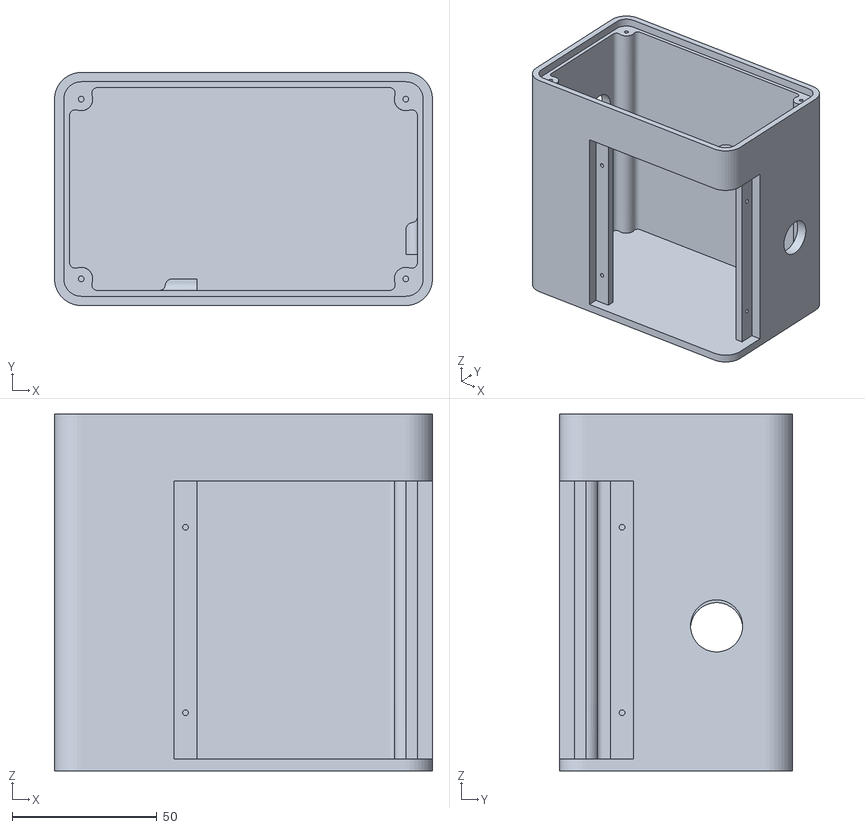
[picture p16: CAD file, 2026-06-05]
Hardware Components/Box/Box Body.stl
130.4 x 80.4 x 123.0

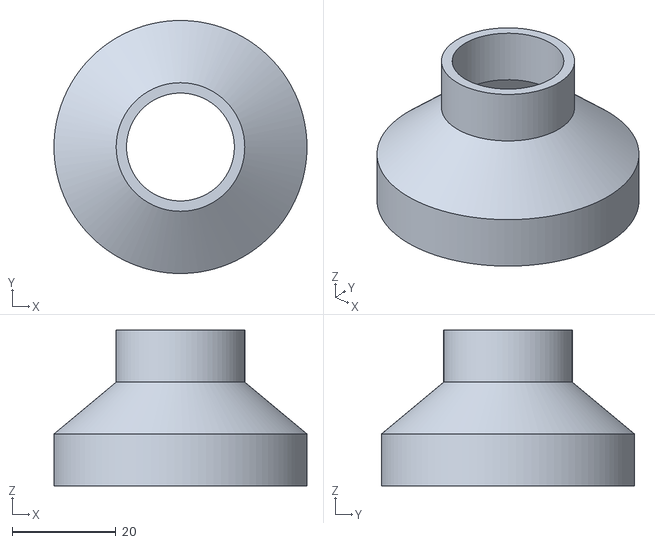
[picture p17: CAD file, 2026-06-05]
Hardware Components/Probe/Sensor Cap.stl
48.8 x 48.8 x 30.0

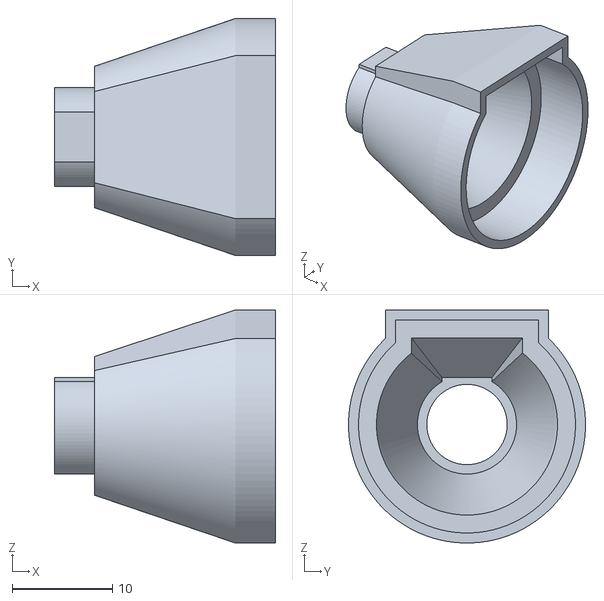
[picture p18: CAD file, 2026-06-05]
Hardware Components/Socket/Wire Cap.stl
22.0 x 23.6 x 23.2

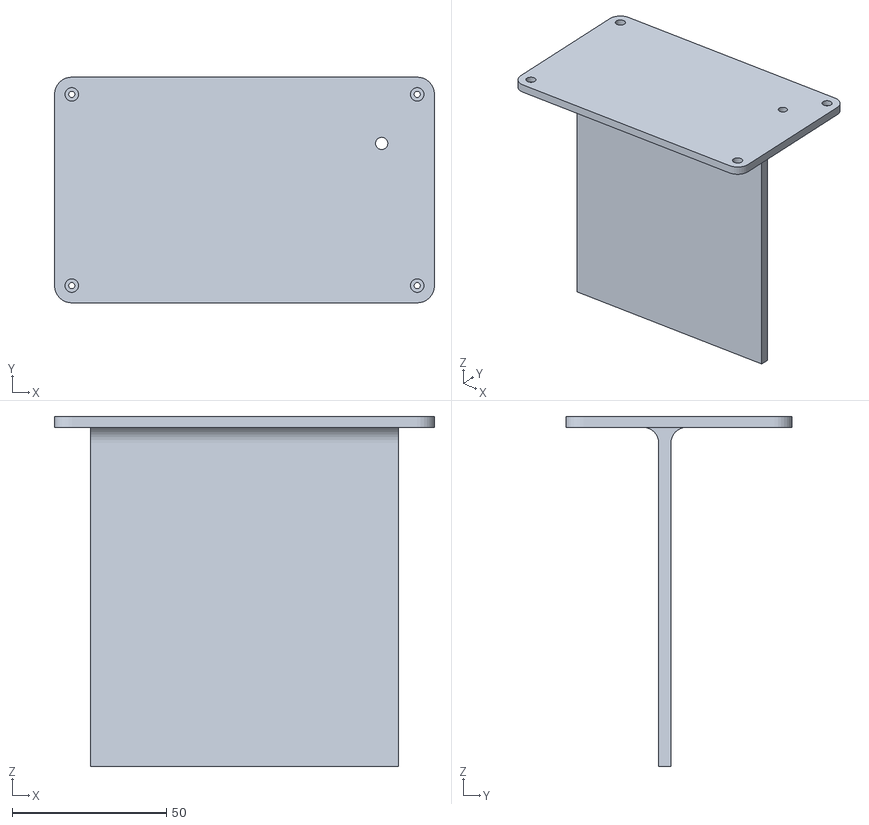
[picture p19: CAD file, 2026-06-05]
Hardware Components/Box/Box Lid.stl
123.2 x 73.2 x 113.6

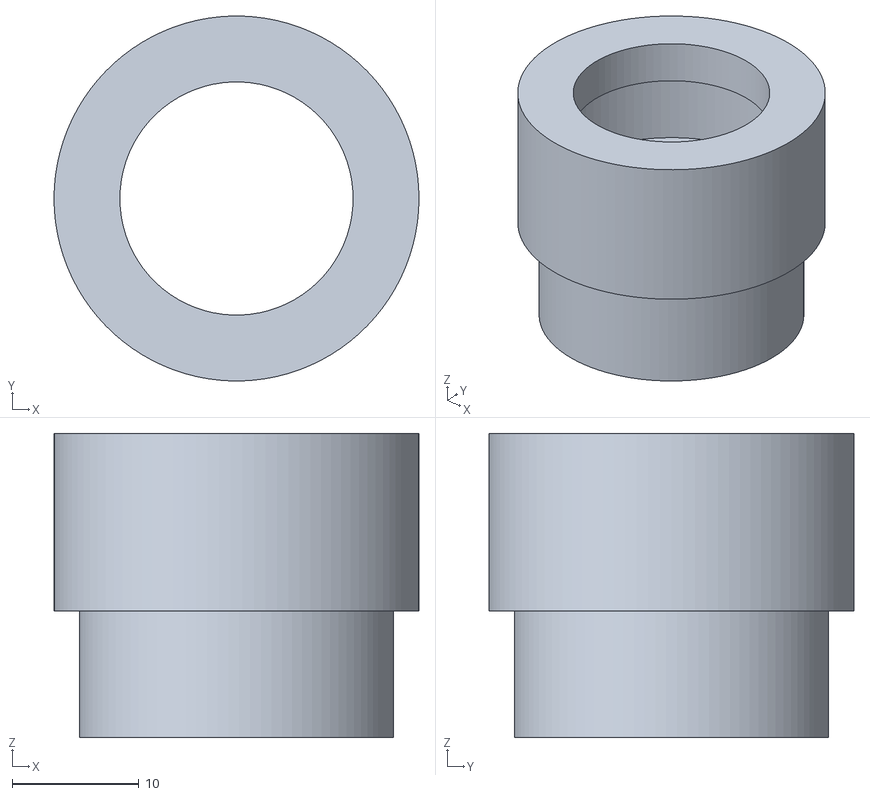
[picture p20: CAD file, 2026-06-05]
Hardware Components/Probe/Probe Port.stl
28.8 x 28.8 x 24.0

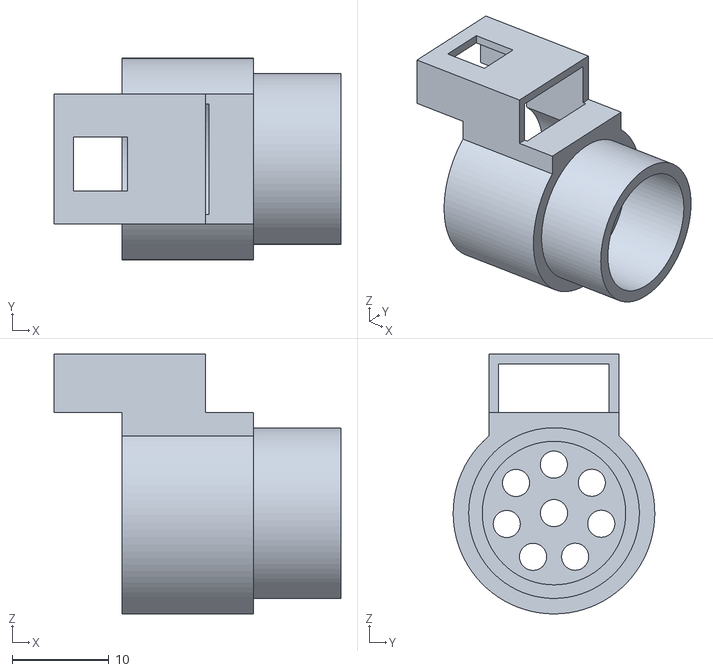
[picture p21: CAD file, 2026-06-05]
Hardware Components/Socket/Female Socket 8 pin.stl
29.6 x 20.8 x 26.8

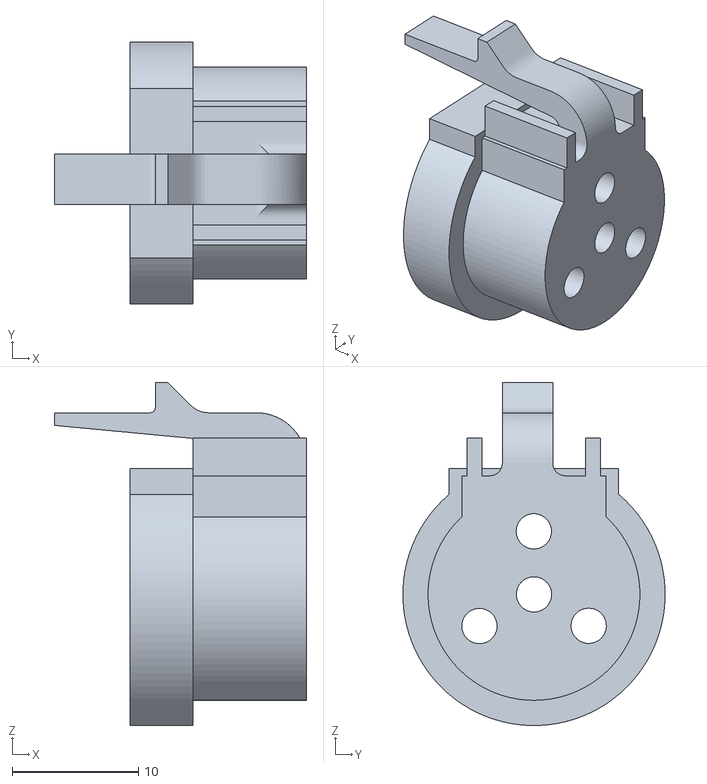
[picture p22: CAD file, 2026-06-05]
Hardware Components/Socket/Male Plug 4 pin.stl
20.0 x 20.8 x 27.2

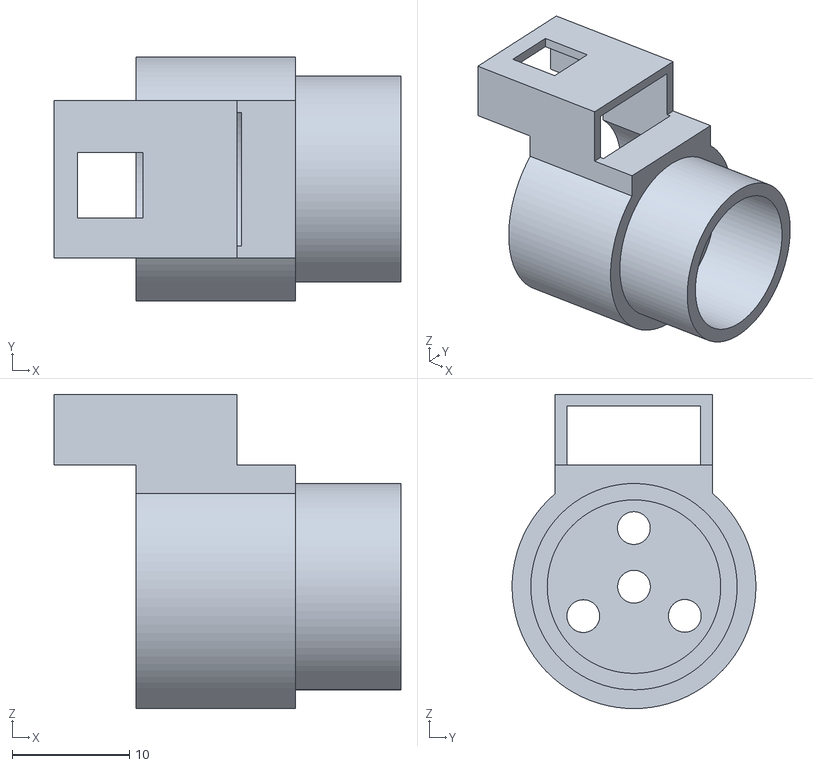
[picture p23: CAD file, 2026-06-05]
Hardware Components/Socket/Female Socket 4 pin.stl
29.6 x 20.8 x 26.8

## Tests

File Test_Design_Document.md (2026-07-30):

# SlideSense Test Design Document

## 1. Project Modules and Use Cases Review
The SlideSense system consists of several key modules that work together to provide early warning landslide detection and monitoring:
*   **Authentication & Authorization Module**: Handles user registration, login, token generation, and role-based access control (Resident, Researcher, Admin).
*   **Probe Management Module**: Manages the deployment, status tracking, and configuration of IoT sensor probes in the field.
*   **Data Ingestion & Retrieval Module**: Responsible for collecting, storing, and serving sensor readings (moisture, tilt, vibration) from the probes to the frontend dashboards securely.

## 2. Selected Critical Functions
Based on our project's requirements and the test suite we have already implemented, we have selected four critical business logic functions for detailed test modeling. These functions are central to system security, data integrity, and device management:
1.  `AuthService.register(RegisterRequest request)` - Handles new user registration requests and complex role-specific validation.
2.  `AuthService.login(LoginRequest request)` - Manages user authentication, status validation, and JWT issuance.
3.  `FrontendDataService.fetchMyReadings(...)` - Retrieves personalized, secure sensor data for authenticated users based on specific access grants.
4.  `ProbeAdminService.createProbe(CreateProbeRequest request)` - Manages the creation and registration of new IoT hardware probes in the system.

---

## 3. Test Design Techniques Application

### 3.1. Function: `AuthService.register(RegisterRequest request)`
**Assigned Group Member:** [Enter Member 1 Name] - [Enter Index Number]

*   **Equivalence Partitioning:**
    *   **Class 1 (Valid Resident):** `RequestedRole` is `RESIDENT`, provides a valid existing `probeId`. (Representative value: Valid resident details with `probe-123`) ➔ *Expected: Success, user created with pending admin approval status.*
    *   **Class 2 (Valid Researcher):** `RequestedRole` is `RESEARCHER`, `probeId` is null/empty. (Representative value: Valid researcher details without probe) ➔ *Expected: Success, registration request created.*
    *   **Class 3 (Invalid Registration):** Email already exists in the system database. ➔ *Expected: Failure (Exception: "Email is already registered").*
    *   **Class 4 (Invalid Role Combination):** `RequestedRole` is `RESEARCHER`, but provides a `probeId`. ➔ *Expected: Failure (Exception: "probeId must not be provided for researcher requests").*

*   **Boundary Value Analysis (Password & Inputs):**
    *   *Just inside the boundary:* Password length of exactly 8 characters (minimum valid length).
    *   *Exactly on the boundary:* Password length of 7 characters (just below minimum). ➔ *Expected: Validation error / Rejection.*
    *   *Just outside the boundary:* Empty string `""` for mandatory fields like email or name. ➔ *Expected: Validation error.*

*   **Error / Negative Cases:**
    *   Invalid email format (e.g., "test@.com", "user@domain").
    *   Null request payload passed to the function.
    *   Non-existent `probeId` provided by a resident.

*   **External Dependencies to Mock/Stub:**
    *   `UserRepository` (to mock `findByEmail` and `save`)
    *   `ProbeRepository` (to mock `findByProbeId`)
    *   `RegistrationRequestRepository` (to mock `save`)
    *   `PasswordEncoder` (to stub password hashing logic)

---

### 3.2. Function: `AuthService.login(LoginRequest request)`
**Assigned Group Member:** [Enter Member 2 Name] - [Enter Index Number]

*   **Equivalence Partitioning:**
    *   **Class 1 (Valid Credentials, Approved User):** Correct email and password, user registration status is `APPROVED`. ➔ *Expected: Success, returns JWT Access and Refresh tokens.*
    *   **Class 2 (Valid Credentials, Unapproved User):** Correct email and password, but user is disabled/pending admin approval. ➔ *Expected: Failure (Exception: "Account is not approved yet").*
    *   **Class 3 (Invalid Credentials):** Incorrect email or password. ➔ *Expected: Failure (Exception: "Invalid credentials").*

*   **Boundary Value Analysis (Token Expiration & Inputs):**
    *   Testing the JWT generation configuration at exactly the boundary of expiration limits (e.g., exact millisecond limits for access tokens).
    *   Input boundaries: Password string of length 1 vs. completely empty string `""`.

*   **Error / Negative Cases:**
    *   Null or empty email/password in the request payload.
    *   `AuthenticationManager` inherently throwing a `DisabledException` due to locked accounts.
    *   `AuthenticationManager` throwing a `BadCredentialsException`.

*   **External Dependencies to Mock/Stub:**
    *   `UserRepository` (to find user details by email)
    *   `AuthenticationManager` (to stub the actual Spring Security authentication process and simulate exceptions)
    *   `JwtService` (to mock token generation methods and expiration configurations)

---

### 3.3. Function: `FrontendDataService.fetchMyReadings(String email, Integer limit, ...)`
**Assigned Group Member:** [Enter Member 3 Name] - [Enter Index Number]

*   **Equivalence Partitioning:**
    *   **Class 1 (Authorized with Data):** Valid user email, user has an active `ProbeAccessGrant`, and the probe has recorded data in the requested timeframe. ➔ *Expected: Returns a populated list of `FrontendReadingDTO`.*
    *   **Class 2 (Authorized with No Data):** Valid user, has access grant, but no sensor readings exist for that probe in the given timeframe. ➔ *Expected: Returns an empty list `[]`.*
    *   **Class 3 (Unauthorized/Unknown User):** User email does not exist in the database or the user has no valid access grants. ➔ *Expected: Returns an empty list `[]`.*

*   **Boundary Value Analysis (Limit Parameter):**
    *   `limit = 1`: Just inside minimum valid range. ➔ *Expected: Retrieves exactly 1 most recent record.*
    *   `limit = 0` or negative: Just outside valid range. ➔ *Expected: Handled gracefully (either validation error or defaults to a standard limit).*
    *   `limit = MAX_INT` or very high number (e.g., 10000): Upper boundary. ➔ *Expected: Retrieves all available records without crashing the system or times out securely.*

*   **Error / Negative Cases:**
    *   Null email provided to the service layer.
    *   Malformed timestamp filters (if applicable to the overloaded method).
    *   Database connection timeout when fetching extremely large datasets.

*   **External Dependencies to Mock/Stub:**
    *   `UserRepository` (to mock `findByEmail`)
    *   `ProbeAccessGrantRepository` (to mock `findByUser_IdAndRevokedAtIsNull`)
    *   `SensorReadingRepository` (to mock `findByProbe_IdAndRecordedAtBetweenOrderByRecordedAtDesc`)

---

### 3.4. Function: `ProbeAdminService.createProbe(CreateProbeRequest request)`
**Assigned Group Member:** [Enter Member 4 Name] - [Enter Index Number]

*   **Equivalence Partitioning:**
    *   **Class 1 (Valid New Probe):** Unique `probeId` and unique `hwSerial` provided with valid coordinates. ➔ *Expected: Success, probe saved to database.*
    *   **Class 2 (Duplicate Probe ID):** `probeId` already exists in the system. ➔ *Expected: Failure (Exception: "Probe ID already exists").*
    *   **Class 3 (Duplicate Hardware Serial):** `hwSerial` already exists for another probe. ➔ *Expected: Failure (Exception: "Hardware Serial already exists").*

*   **Boundary Value Analysis (Coordinates & Inputs):**
    *   *Latitude & Longitude boundaries:* Testing exact maximum/minimum coordinate values (e.g., Latitude 90.0 and -90.0, Longitude 180.0 and -180.0).
    *   *Input boundaries:* Empty strings `""` for `probeId` or `hwSerial`. ➔ *Expected: Validation error.*

*   **Error / Negative Cases:**
    *   Null request payload.
    *   Missing mandatory fields in `CreateProbeRequest` (e.g., status is null).
    *   Database connection issues during repository save.

*   **External Dependencies to Mock/Stub:**
    *   `ProbeRepository` (to mock `findByProbeId`, `findByHwSerial`, and `save` methods)

---
*Note to team: Please update the [Enter Member Name] and [Enter Index Number] placeholders with your actual details before submission.*

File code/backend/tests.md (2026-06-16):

# Backend Testing Walkthrough

I have successfully added a comprehensive suite of unit and integration tests for the core authentication and data retrieval layers of the backend. 

All 25 tests in the suite are now passing successfully!

## What Was Added

### 1. Services (Unit Tests)
We added isolated unit tests for the core business logic using JUnit 5 and Mockito. This ensures the services behave correctly under various conditions without needing a database connection.

- **[AuthServiceTest.java](file:///home/fikry/dev/e21-3yp-SlideSense/code/backend/src/test/java/com/slidesense/backend/service/AuthServiceTest.java)**
  - `register`: Verified successful registration flows, prevention of duplicate emails, and constraints (e.g., researchers cannot provide probe IDs).
  - `login`: Verified successful authentication, proper token generation, and correct handling of disabled accounts or bad credentials.
  - `refresh`: Verified refresh token extraction, validation, and issuance of new JWT tokens.
- **[FrontendDataServiceTest.java](file:///home/fikry/dev/e21-3yp-SlideSense/code/backend/src/test/java/com/slidesense/backend/service/FrontendDataServiceTest.java)**
  - `fetchAllReadings`: Verified that the service correctly fetches readings for all active probes.
  - `fetchMyReadings`: Verified that users only receive readings for probes they have explicit access grants for.
  - `fetchLatestSimple`: Verified the logic for fetching the most recent simplified sensor reading.

### 2. Controllers (Slice Tests)
We added integration tests for the REST API endpoints using `MockMvcBuilders.standaloneSetup()`. This approach bypasses the full Spring context (and security filters), making the tests extremely fast while still validating JSON serialization, HTTP status codes, and endpoint routing.

- **[AuthControllerTest.java](file:///home/fikry/dev/e21-3yp-SlideSense/code/backend/src/test/java/com/slidesense/backend/controller/AuthControllerTest.java)**
  - Verified POST requests to `/auth/register`, `/auth/login`, `/auth/refresh`, and `/auth/logout`.
  - Asserted that the JSON response bodies contain the correct fields (e.g., `accessToken`, `user.role`, `message`).
- **[ProbeDataControllerTest.java](file:///home/fikry/dev/e21-3yp-SlideSense/code/backend/src/test/java/com/slidesense/backend/controller/ProbeDataControllerTest.java)**
  - Verified GET requests to `/api/v1/probes/readings`, `/api/v1/probes/my-readings`, and `/api/v1/probes/latest`.
  - Used `TestingAuthenticationToken` to mock the authenticated user principal.
  - Asserted the structure of the JSON responses.

## Validation Results

> [!TIP]
> **Build Success**
> Running `./mvnw test -Dtest=AuthServiceTest,FrontendDataServiceTest,AuthControllerTest,ProbeDataControllerTest,ProbeAdminServiceTest,AlertControllerTest` resulted in a successful execution of all 25 tests in just under 8 seconds.

```text
[INFO] Tests run: 25, Failures: 0, Errors: 0, Skipped: 0
[INFO] ------------------------------------------------------------------------
[INFO] BUILD SUCCESS
[INFO] ------------------------------------------------------------------------
```

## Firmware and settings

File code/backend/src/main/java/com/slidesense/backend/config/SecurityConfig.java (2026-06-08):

package com.slidesense.backend.config;

import com.slidesense.backend.security.ApiKeyAuthenticationFilter;
import com.slidesense.backend.security.CustomUserDetailsService;
import com.slidesense.backend.security.JwtAuthenticationFilter;
import jakarta.servlet.http.HttpServletResponse;
import org.slf4j.Logger;
import org.slf4j.LoggerFactory;
import org.springframework.context.annotation.Bean;
import org.springframework.context.annotation.Configuration;
import org.springframework.security.authentication.AuthenticationManager;
import org.springframework.security.authentication.AuthenticationProvider;
import org.springframework.security.authentication.dao.DaoAuthenticationProvider;
import org.springframework.security.config.annotation.authentication.configuration.AuthenticationConfiguration;
import org.springframework.security.config.annotation.method.configuration.EnableMethodSecurity;
import org.springframework.security.config.annotation.web.builders.HttpSecurity;
import org.springframework.security.config.http.SessionCreationPolicy;
import org.springframework.security.crypto.bcrypt.BCryptPasswordEncoder;
import org.springframework.security.crypto.password.PasswordEncoder;
import org.springframework.security.web.SecurityFilterChain;
import org.springframework.security.web.authentication.UsernamePasswordAuthenticationFilter;
import org.springframework.web.cors.CorsConfiguration;
import org.springframework.web.cors.CorsConfigurationSource;
import org.springframework.web.cors.UrlBasedCorsConfigurationSource;
import java.util.Arrays;

@Configuration
@EnableMethodSecurity
public class SecurityConfig {

    private static final Logger log = LoggerFactory.getLogger(SecurityConfig.class);

    @Bean
    public SecurityFilterChain securityFilterChain(
        HttpSecurity http,
        JwtAuthenticationFilter jwtAuthenticationFilter,
        ApiKeyAuthenticationFilter apiKeyAuthenticationFilter,
        AuthenticationProvider authenticationProvider
    ) throws Exception {
        http
            .cors(cors -> cors.configurationSource(corsConfigurationSource()))
            .csrf(csrf -> csrf.disable())
            .sessionManagement(session -> session.sessionCreationPolicy(SessionCreationPolicy.STATELESS))
            .authenticationProvider(authenticationProvider)
            .exceptionHandling(exception ->
                exception
                    .authenticationEntryPoint((request, response, authException) -> {
                        log.warn(
                            "401 Unauthorized for {} {}. Reason: {}",
                            request.getMethod(),
                            request.getRequestURI(),
                            authException.getMessage()
                        );
                        response.sendError(HttpServletResponse.SC_UNAUTHORIZED, "Unauthorized");
                    })
                    .accessDeniedHandler((request, response, accessDeniedException) -> {
                        String principal =
                            request.getUserPrincipal() != null ? request.getUserPrincipal().getName() : "anonymous";
                        log.warn(
                            "403 Forbidden for {} {}. Principal: {}. Reason: {}",
                            request.getMethod(),
                            request.getRequestURI(),
                            principal,
                            accessDeniedException.getMessage()
                        );
                        response.sendError(HttpServletResponse.SC_FORBIDDEN, "Forbidden");
                    })
            )
            .authorizeHttpRequests(auth ->
                auth
                    .requestMatchers(
                        "/v3/api-docs/**",
                        "/swagger-ui/**",
                        "/swagger-ui.html",
                        "/actuator/health",
                        "/auth/register",
                        "/auth/login",
                        "/auth/refresh",
                        "/ingestion/http",
                        "/error"
                    )
                    .permitAll()
                    .requestMatchers("/api/v1/public/**")
                    .hasRole("API_CLIENT")
                    .requestMatchers("/admin/**")
                    .hasRole("ADMIN")
                    .requestMatchers("/users/**", "/auth/logout")
                    .authenticated()
                    .anyRequest()
                    .authenticated()
            )
            .addFilterBefore(apiKeyAuthenticationFilter, UsernamePasswordAuthenticationFilter.class)
            .addFilterBefore(jwtAuthenticationFilter, UsernamePasswordAuthenticationFilter.class);

        return http.build();
    }

    @Bean
    public CorsConfigurationSource corsConfigurationSource() {
        CorsConfiguration configuration = new CorsConfiguration();
        configuration.setAllowedOrigins(Arrays.asList("http://localhost:5173", "http://localhost:3000"));
        configuration.setAllowedMethods(Arrays.asList("GET", "POST", "PUT", "PATCH", "DELETE", "OPTIONS"));
        configuration.setAllowedHeaders(Arrays.asList("Authorization", "Content-Type", "x-api-key"));
        configuration.setExposedHeaders(Arrays.asList("Authorization"));
        configuration.setAllowCredentials(true);
        UrlBasedCorsConfigurationSource source = new UrlBasedCorsConfigurationSource();
        source.registerCorsConfiguration("/**", configuration);
        return source;
    }

    @Bean
    public AuthenticationProvider authenticationProvider(CustomUserDetailsService userDetailsService) {
        DaoAuthenticationProvider provider = new DaoAuthenticationProvider(userDetailsService);
        provider.setPasswordEncoder(passwordEncoder());
        return provider;
    }

    @Bean
    public AuthenticationManager authenticationManager(AuthenticationConfiguration configuration) throws Exception {
        return configuration.getAuthenticationManager();
    }

    @Bean
    public PasswordEncoder passwordEncoder() {
        return new BCryptPasswordEncoder();
    }
}

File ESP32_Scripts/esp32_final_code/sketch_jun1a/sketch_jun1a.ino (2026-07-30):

#include <Arduino.h>
#include <ArduinoJson.h>
#include <TinyGPS++.h>

// =========================
// TUNABLE INTERVALS
// =========================
constexpr uint32_t POLLING_INTERVAL_MS = 2000;
constexpr uint32_t PUBLISH_INTERVAL_MS = 10000;

// Each hall-effect pulse represents one bucket tip.
// Keep this configurable in case the rain gauge is recalibrated.
constexpr float RAIN_MM_PER_TIP = 0.173f;

constexpr int RAIN_THRESHOLD_HIGH = 2020;
constexpr int RAIN_THRESHOLD_LOW  = 1900;

// Moisture calibration values. Update after field calibration.
constexpr int MOISTURE_RAW_DRY = 3200;
constexpr int MOISTURE_RAW_WET = 1400;

// Hardware wiring.
constexpr int SIM808_RX_PIN = 17; // Updated
constexpr int SIM808_TX_PIN = 16; // Updated
constexpr int GPS_RX_PIN = 25;    // Swapped to avoid conflict
constexpr int GPS_TX_PIN = 26;    // Swapped to avoid conflict
constexpr int MOISTURE_PIN = 34;
constexpr int RAIN_PIN = 27;

// HTTP target. Replace API_HOST with the backend host or IP.
// This path matches the HTTP ingestion endpoint added to the backend.
constexpr const char* API_HOST = "3.7.191.76";
constexpr uint16_t API_PORT = 80;
constexpr const char* API_PATH = "/ingestion/http";
constexpr const char* GSM_APN = "mobitel";
constexpr const char* BRIDGE_SECRET = "278075eb4912a22ff8c6590ddc69adc4ac9f9fd47ee9fdbb31da755433c863db";
constexpr const char* PROBE_ID = "P-TEST-01";
constexpr const char* HW_SERIAL = "SN-TEST-01";

// =========================
// SERIAL PORTS AND GPS
// =========================
HardwareSerial SerialGsm(2);
HardwareSerial SerialGps(1);
TinyGPSPlus gps;

// =========================
// SENSOR STATE SHARED ACROSS CORES
// =========================
struct SensorSnapshot {
  uint64_t deviceTimeMs;
  float moisture;
  float tiltAngle;
  float vibrationMag;
  float rainfallMm;
  uint32_t tipCount;
  float totalRainfallMm;
  uint32_t sequence;
};

constexpr size_t HISTORY_SIZE = 16;

SensorSnapshot latestSnapshot{};
SensorSnapshot historyBuffer[HISTORY_SIZE];
size_t historyHead = 0;
size_t historyCount = 0;

SemaphoreHandle_t stateMutex = nullptr;

volatile uint32_t rainTipCount = 0;
bool rainWasHigh = false;

struct GpsClockState {
  bool valid = false;
  uint64_t epochMs = 0;
  uint32_t syncedAtMillis = 0;
};

GpsClockState gpsClockState;

// =========================
// HELPERS
// =========================
void rainTask(void* parameter) {
  (void)parameter;
  for (;;) {
    int analogValue = analogRead(RAIN_PIN);

    // Determine state using hysteresis instead of a single threshold
    bool isHigh = rainWasHigh; // default: stay in current state
    if (!rainWasHigh && analogValue > RAIN_THRESHOLD_HIGH) {
      isHigh = true;
    } else if (rainWasHigh && analogValue < RAIN_THRESHOLD_LOW) {
      isHigh = false;
    }

    // Check for state change (the tip)
    if (isHigh != rainWasHigh) {
      rainTipCount++;
      rainWasHigh = isHigh;
      vTaskDelay(pdMS_TO_TICKS(50)); // debounce
    }

    vTaskDelay(pdMS_TO_TICKS(10));
  }
}

static int64_t daysFromCivil(int year, unsigned month, unsigned day) {
  year -= month <= 2;
  const int era = (year >= 0 ? year : year - 399) / 400;
  const unsigned yearOfEra = static_cast<unsigned>(year - era * 400);
  const unsigned dayOfYear = (153 * (month + (month > 2 ? -3 : 9)) + 2) / 5 + day - 1;
  const unsigned dayOfEra = yearOfEra * 365 + yearOfEra / 4 - yearOfEra / 100 + dayOfYear;
  return static_cast<int64_t>(era) * 146097 + static_cast<int64_t>(dayOfEra) - 719468;
}

uint64_t gpsToEpochMs() {
  if (!gps.date.isValid() || !gps.time.isValid()) {
    return 0;
  }

  int year = gps.date.year();
  unsigned month = gps.date.month();
  unsigned day = gps.date.day();
  int hour = gps.time.hour();
  int minute = gps.time.minute();
  int second = gps.time.second();
  int centisecond = gps.time.centisecond();

  int64_t days = daysFromCivil(year, month, day);
  int64_t seconds = days * 86400LL + hour * 3600LL + minute * 60LL + second;
  return static_cast<uint64_t>(seconds) * 1000ULL + static_cast<uint64_t>(centisecond) * 10ULL;
}

uint64_t currentDeviceTimeMs() {
  if (gpsClockState.valid) {
    return gpsClockState.epochMs + (static_cast<uint64_t>(millis()) - gpsClockState.syncedAtMillis);
  }
  return static_cast<uint64_t>(millis());
}

float readMoisturePercent() {
  int raw = analogRead(MOISTURE_PIN);
  float percent = (static_cast<float>(MOISTURE_RAW_DRY - raw) * 100.0f) /
                  static_cast<float>(MOISTURE_RAW_DRY - MOISTURE_RAW_WET);
  if (percent < 0.0f) percent = 0.0f;
  if (percent > 100.0f) percent = 100.0f;
  return percent;
}

void pushSnapshotToHistory(const SensorSnapshot& snapshot) {
  if (historyCount < HISTORY_SIZE) {
    historyCount++;
  }
  historyBuffer[historyHead] = snapshot;
  historyHead = (historyHead + 1) % HISTORY_SIZE;
}

void updateGpsClock() {
  uint64_t epochMs = gpsToEpochMs();
  if (epochMs != 0) {
    gpsClockState.valid = true;
    gpsClockState.epochMs = epochMs;
    gpsClockState.syncedAtMillis = millis();
  }
}

void drainSerial(HardwareSerial& serialPort) {
  while (serialPort.available()) {
    serialPort.read();
  }
}

bool waitForToken(HardwareSerial& serialPort, const char* token, uint32_t timeoutMs) {
  String response;
  uint32_t start = millis();

  while (millis() - start < timeoutMs) {
    while (serialPort.available()) {
      response += static_cast<char>(serialPort.read());
      if (response.indexOf(token) >= 0) {
        return true;
      }
      if (response.indexOf("ERROR") >= 0) {
        return false;
      }
    }
    delay(10);
  }

  return response.indexOf(token) >= 0;
}

bool sendAT(const String& command, const char* expected, uint32_t timeoutMs) {
  drainSerial(SerialGsm);
  Serial.print("[MODEM] AT -> ");
  Serial.println(command);
  SerialGsm.println(command);
  bool ok = waitForToken(SerialGsm, expected, timeoutMs);
  Serial.print("[MODEM] Result: ");
  Serial.println(ok ? "OK" : "FAIL");
  return ok;
}

bool gsmInit() {
  Serial.println("[MODEM] Initializing SIM808 data session...");
  if (!sendAT("AT", "OK", 2000)) {
    Serial.println("[MODEM] SIM808 not responding");
    return false;
  }
  sendAT("ATE0", "OK", 2000);
  sendAT("AT+CMEE=2", "OK", 2000);
  sendAT("AT+SAPBR=3,1,\"Contype\",\"GPRS\"", "OK", 3000);

  String apnCommand = "AT+SAPBR=3,1,\"APN\",\"";
  apnCommand += GSM_APN;
  apnCommand += "\"";
  sendAT(apnCommand, "OK", 3000);

  sendAT("AT+SAPBR=1,1", "OK", 15000);
  sendAT("AT+SAPBR=2,1", "OK", 5000);
  Serial.println("[MODEM] SIM808 ready for HTTP publish");
  return true;
}

bool postJsonPayload(const String& jsonPayload) {
  Serial.print("[PUBLISH] Payload bytes: ");
  Serial.println(jsonPayload.length());

  if (!sendAT("AT+CIPSHUT", "SHUT OK", 10000)) {
    // Some SIM808 firmwares return ERROR when no PDP context is active.
    // That is acceptable, so continue.
  }

  sendAT("AT+CIPMUX=0", "OK", 3000);
  sendAT("AT+CIPMODE=0", "OK", 3000);

  String startCommand = "AT+CIPSTART=\"TCP\",\"";
  startCommand += API_HOST;
  startCommand += "\",";
  startCommand += API_PORT;

  Serial.print("[PUBLISH] Connecting to ");
  Serial.print(API_HOST);
  Serial.print(":");
  Serial.println(API_PORT);

  if (!sendAT(startCommand, "CONNECT OK", 20000)) {
    Serial.println("[PUBLISH] TCP connection failed");
    return false;
  }

  String httpRequest;
  httpRequest.reserve(jsonPayload.length() + 256);
  httpRequest += "POST ";
  httpRequest += API_PATH;
  httpRequest += " HTTP/1.1\r\nHost: ";
  httpRequest += API_HOST;
  httpRequest += "\r\nX-Bridge-Secret: ";
  httpRequest += BRIDGE_SECRET;
  httpRequest += "\r\nContent-Type: application/json\r\nConnection: close\r\nContent-Length: ";
  httpRequest += jsonPayload.length();
  httpRequest += "\r\n\r\n";
  httpRequest += jsonPayload;

  String sendCommand = "AT+CIPSEND=";
  sendCommand += httpRequest.length();
  if (!sendAT(sendCommand, ">", 5000)) {
    Serial.println("[PUBLISH] CIPSEND prompt not received");
    sendAT("AT+CIPCLOSE", "CLOSE OK", 5000);
    return false;
  }

  Serial.println("[PUBLISH] Exact HTTP packet:");
  Serial.print(httpRequest);
  Serial.println();
  Serial.println("[PUBLISH] Sending HTTP POST request");
  SerialGsm.print(httpRequest);

  bool sent = waitForToken(SerialGsm, "SEND OK", 10000);
  Serial.println(sent ? "[PUBLISH] HTTP request sent" : "[PUBLISH] HTTP send failed");
  waitForToken(SerialGsm, "CLOSED", 3000);
  sendAT("AT+CIPCLOSE", "CLOSE OK", 5000);
  return sent;
}

String buildPayload(const SensorSnapshot& snapshot) {
  StaticJsonDocument<256> doc;
  doc["probe_id"] = PROBE_ID;
  doc["deviceTimeMs"] = snapshot.deviceTimeMs;
  doc["moisture"] = snapshot.moisture;
  doc["tiltAngle"] = snapshot.tiltAngle;
  doc["vibrationMag"] = snapshot.vibrationMag;
  doc["samplingMode"] = "Normal";
  doc["rainfallMm"] = snapshot.totalRainfallMm;
  doc["hwSerial"] = HW_SERIAL;

  String jsonPayload;
  serializeJson(doc, jsonPayload);
  return jsonPayload;
}

void sensorTask(void* parameter) {
  (void)parameter;

  uint32_t sequence = 0;
  Serial.println("[INIT] Core 1 polling task initialized");

  for (;;) {
    while (SerialGps.available()) {
      gps.encode(SerialGps.read());
      if (gps.location.isUpdated() || gps.date.isUpdated() || gps.time.isUpdated()) {
        updateGpsClock();
        Serial.println("[GPS] Time fix updated");
      }
    }

    uint32_t tipCountSnapshot;
    noInterrupts();
    tipCountSnapshot = rainTipCount;
    interrupts();

    SensorSnapshot snapshot{};
    snapshot.deviceTimeMs = currentDeviceTimeMs();
    snapshot.moisture = readMoisturePercent();
    snapshot.tiltAngle = 0.0f;
    snapshot.vibrationMag = 0.0f;
    snapshot.tipCount = tipCountSnapshot;
    snapshot.totalRainfallMm = static_cast<float>(tipCountSnapshot) * RAIN_MM_PER_TIP;
    snapshot.rainfallMm = snapshot.totalRainfallMm;
    snapshot.sequence = ++sequence;

    Serial.printf(
      "[SENSOR] seq=%lu moisture=%.2f%% tips=%lu rainfall=%.3fmm timeMs=%llu\n",
      static_cast<unsigned long>(snapshot.sequence),
      snapshot.moisture,
      static_cast<unsigned long>(snapshot.tipCount),
      snapshot.totalRainfallMm,
      static_cast<unsigned long long>(snapshot.deviceTimeMs)
    );

    if (xSemaphoreTake(stateMutex, portMAX_DELAY) == pdTRUE) {
      latestSnapshot = snapshot;
      pushSnapshotToHistory(snapshot);
      xSemaphoreGive(stateMutex);
    }

    vTaskDelay(pdMS_TO_TICKS(POLLING_INTERVAL_MS));
  }
}

void publishTask(void* parameter) {
  (void)parameter;

  Serial.println("[INIT] Core 0 publishing task initialized");
  bool gsmReady = gsmInit();
  uint8_t packetsSent = 0; // New counter to track successful transmissions

  for (;;) {
    // Check if we hit the 10 packet limit
    if (packetsSent >= 10) {
      Serial.println("[PUBLISH] Reached maximum of 10 test packets. Stopping publish task.");
      vTaskDelete(nullptr); // Safely terminates this FreeRTOS task
    }

    SensorSnapshot snapshot;
    if (xSemaphoreTake(stateMutex, portMAX_DELAY) == pdTRUE) {
      snapshot = latestSnapshot;
      xSemaphoreGive(stateMutex);
    }

    if (!gsmReady) {
      Serial.println("[PUBLISH] GSM session not ready, retrying init");
      gsmReady = gsmInit();
    }

    if (gsmReady) {
      String payload = buildPayload(snapshot);
      Serial.print("[PUBLISH] Posting seq=");
      Serial.println(snapshot.sequence);
      if (!postJsonPayload(payload)) {
        Serial.println("[PUBLISH] Publish failed, will re-init modem next cycle");
        gsmReady = false;
      } else {
        Serial.println("[PUBLISH] Publish complete");
        packetsSent++; // Increment the counter upon success
        Serial.printf("[PUBLISH] Packets sent: %d/10\n", packetsSent);
      }
    }

    vTaskDelay(pdMS_TO_TICKS(PUBLISH_INTERVAL_MS));
  }
}

void setup() {
  Serial.begin(115200);
  Serial.println("[BOOT] SlideSense ESP32 logger starting");
  Serial.printf("[BOOT] Poll interval: %lu ms, publish interval: %lu ms\n", POLLING_INTERVAL_MS, PUBLISH_INTERVAL_MS);

  pinMode(MOISTURE_PIN, INPUT);
  analogReadResolution(12);
  analogSetPinAttenuation(MOISTURE_PIN, ADC_11db);

  pinMode(RAIN_PIN, INPUT);
  analogSetPinAttenuation(RAIN_PIN, ADC_11db);
  xTaskCreatePinnedToCore(rainTask, "rainTask", 4096, nullptr, 3, nullptr, 1);

  SerialGsm.begin(9600, SERIAL_8N1, SIM808_RX_PIN, SIM808_TX_PIN);
  SerialGps.begin(9600, SERIAL_8N1, GPS_RX_PIN, GPS_TX_PIN);
  Serial.println("[BOOT] Serial links for SIM808 and GPS initialized");

  stateMutex = xSemaphoreCreateMutex();
  if (stateMutex == nullptr) {
    Serial.println("[BOOT] Failed to create mutex");
    while (true) {
      delay(1000);
    }
  }

  Serial.println("[BOOT] Starting FreeRTOS tasks on separate cores");
  xTaskCreatePinnedToCore(sensorTask, "sensorTask", 8192, nullptr, 2, nullptr, 1);
  xTaskCreatePinnedToCore(publishTask, "publishTask", 12288, nullptr, 1, nullptr, 0);
  Serial.println("[BOOT] Sensor polling pinned to core 1, publishing pinned to core 0");
}

void loop() {
  vTaskDelay(portMAX_DELAY);
}

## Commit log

2026-02-11 Update hardware prototype image in README
2026-02-11 Fix image filename case in README
2026-02-12 Rename WhatsApp Image 2026-02-11 at 23.52.48.jpeg to Probe.jpeg
2026-04-24 Add simple tilt sensor module code
2026-04-24 add calibration code and AWS configuration code
2026-04-26 feat: implemented vibration readings
    [SendData_IoTcoreV1.2.cpp]
2026-04-26 Include deviceID in JSON payload
    Added deviceID to JSON payload for data transmission.
2026-06-03 add gitignore (#36)
    * iot with sqs done, not tested, maven compiled successfully
    * connecting, but errors
    * complete testing nad verfied functionality
    * intialize ESP32 esp idf project
    * set up http communication between esp32 and ec2
    * add gitignore
    [SecurityConfig.java, sketch_jun1a.ino, sketch_may18a.ino]
2026-06-05 Uploaded 3d design model (#37)
    [Battery Lid.stl, Box Body.stl, Box Lid.stl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]
